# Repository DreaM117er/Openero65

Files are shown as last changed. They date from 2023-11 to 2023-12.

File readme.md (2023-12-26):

# OpeNero65

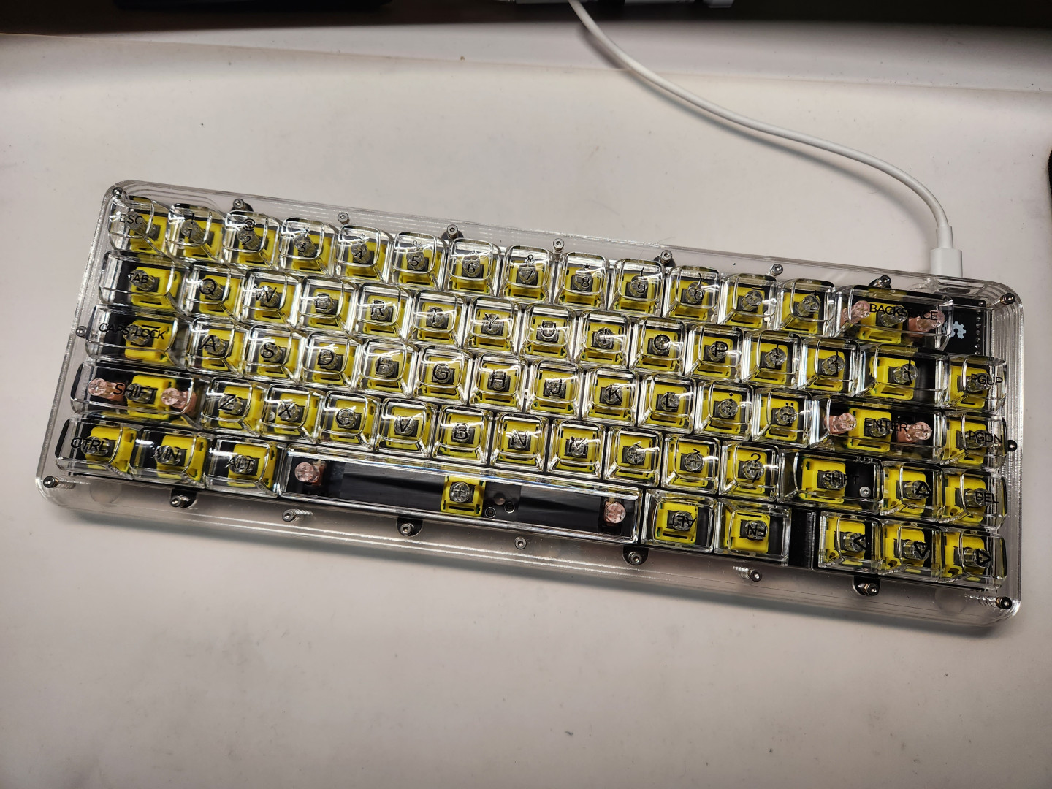
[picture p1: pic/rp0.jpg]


## 一、開發者前言

OpeNero65是我設計的第一把`ANSI配列`鍵盤，使用市面上都能輕易買到的RP2040開發板驅動，支援`QMK`/`VIAL`、多配列支持、階梯CapsLock等。本以為標準鍵盤外殼很好設計，後來發現單件CNC的價格過高，才改用堆疊外殼的設計方式，本次成品會採用3mm厚度壓克力製成。

OpeNero65 is the first `ANSI keyboard` I designed, it is driven by the RP2040 development board which can be easily purchased in the market, and it supports `QMK`/`VIAL`, multi-compatibility support, and ladder CapsLock, etc. Originally, I thought the standard keyboard case is very easy to design, then I found that the price of a single CNC is too high, so I switched to the stacked case design. Originally thought the standard keyboard case is very good design, but later found that the price of a single piece of CNC is too high, and then changed to the stacked case design, the finished product will be made of 3mm thickness acrylic.

設計堆疊殼也相當不輕鬆，特別是PCB階段它有一端是向外突起，接著開發板採用的是排針焊接固定，大大增加堆疊外殼的3D設計困難。仰角以堆疊外殼來說仰角有2種設計方式，但因為開發板固定在PCB上會有立體干涉存在，只能採用橫向堆疊的方式設計... 總體來說也經過一段時間折騰才順利完成。

The design of the stacked case is not easy, especially at the PCB stage it has an end that protrudes outward, and then the development board is fixed with rows of pins, which greatly increases the difficulty of the 3D design of the stacked case. Elevation angle to stack the case of the elevation angle of two design methods, but because the development board fixed on the PCB will have three-dimensional interference exists, can only be used in a horizontal stacking design... Overall, also after a period of time to successfully complete.

## 二、設計圖預覽

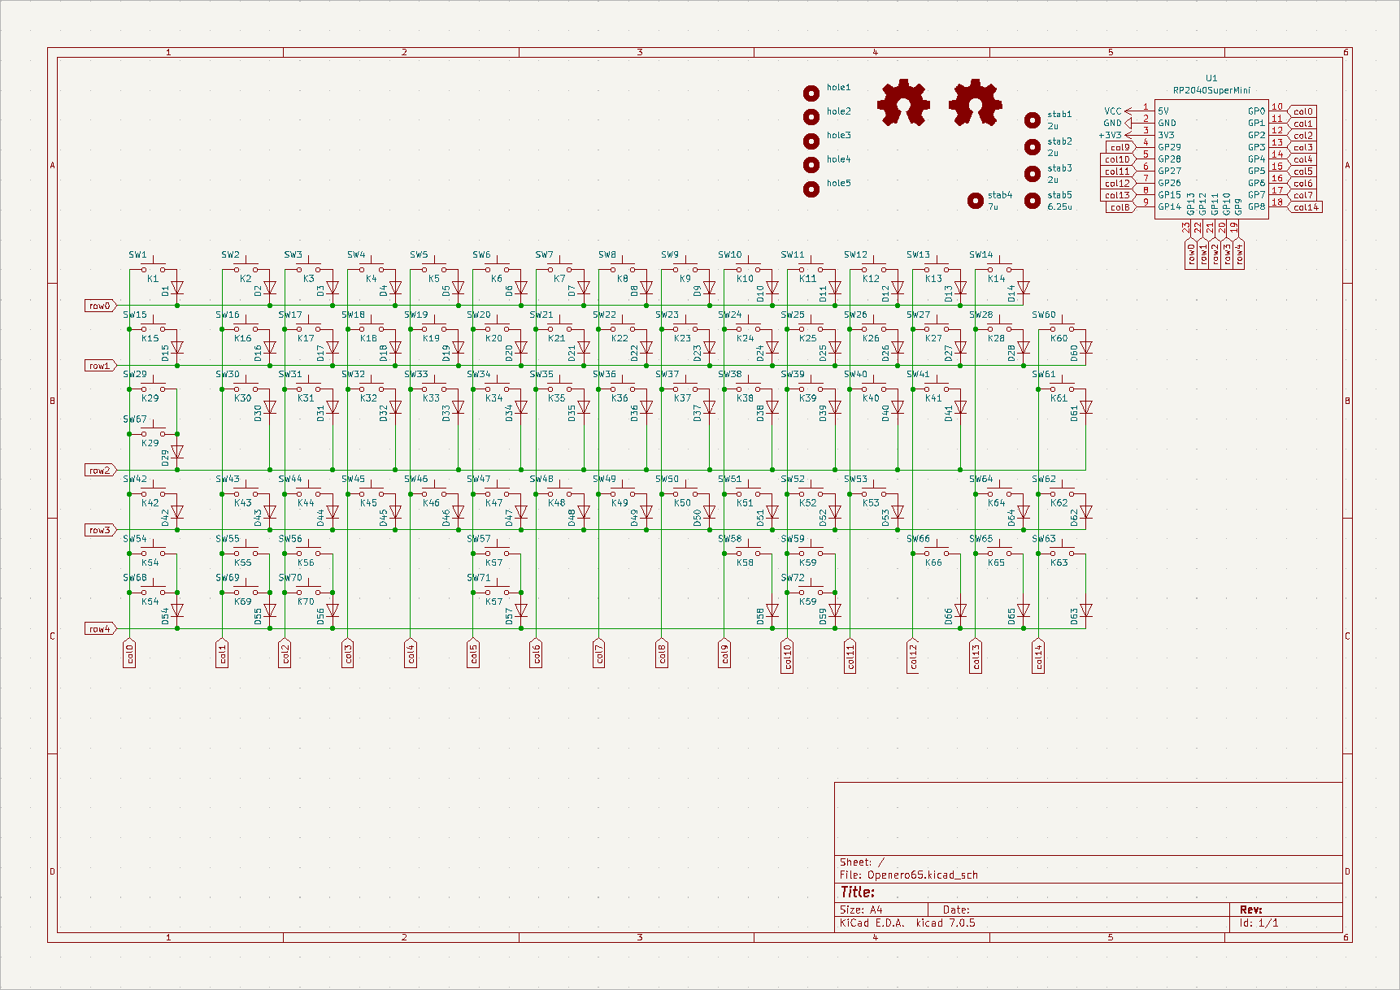
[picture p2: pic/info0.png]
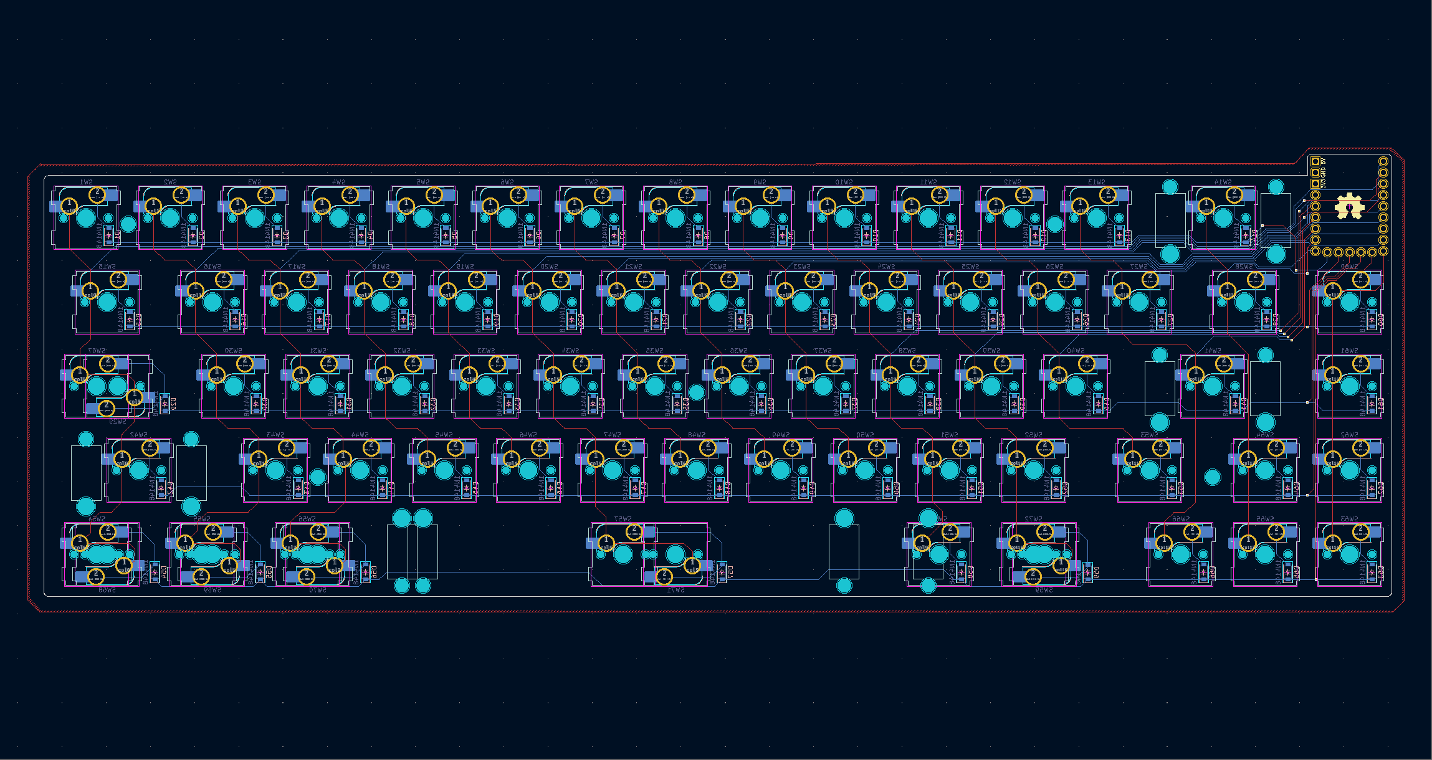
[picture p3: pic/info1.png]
|||
|---|---|
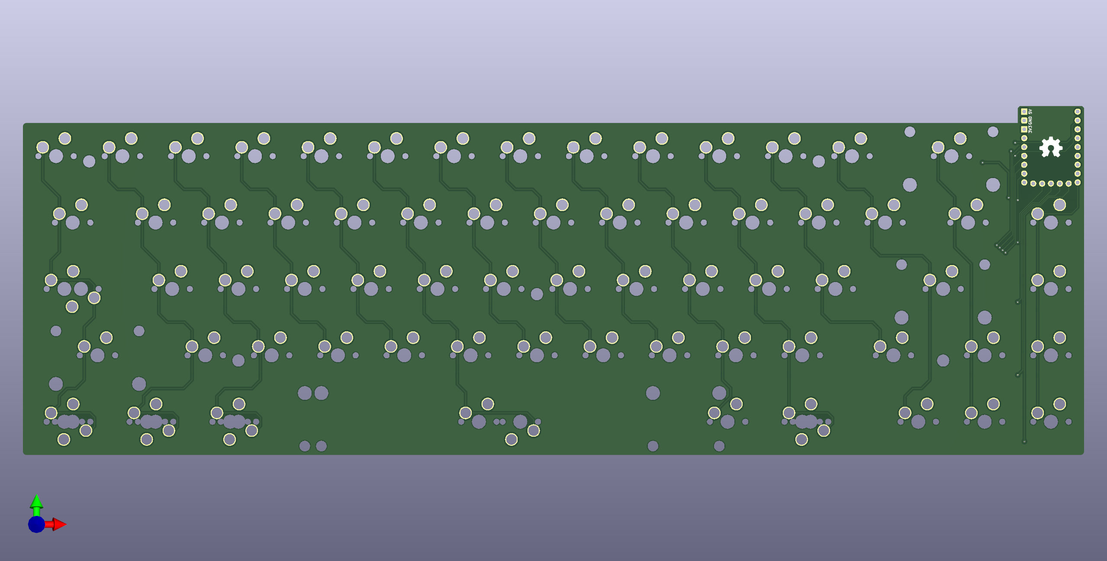
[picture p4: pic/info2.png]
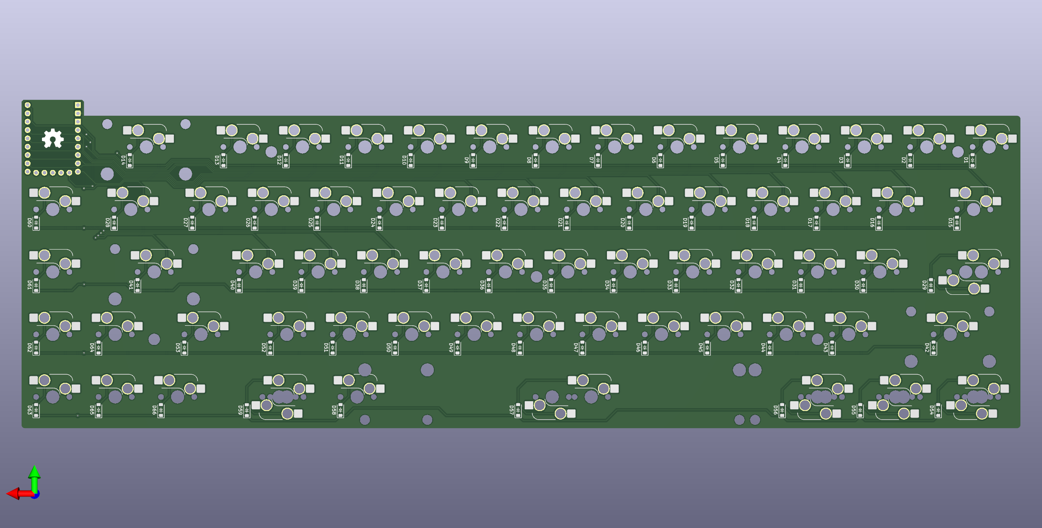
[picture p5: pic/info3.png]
|||
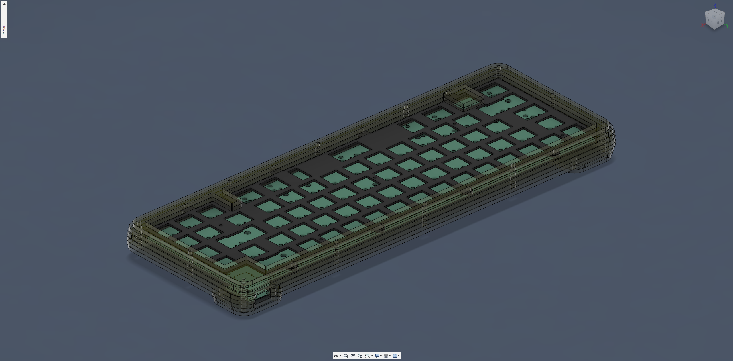
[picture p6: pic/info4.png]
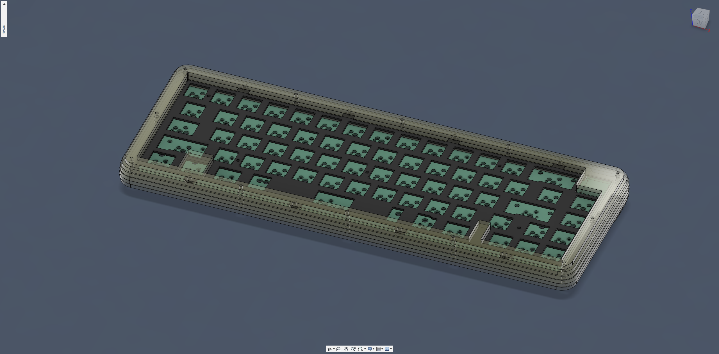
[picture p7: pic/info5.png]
|||
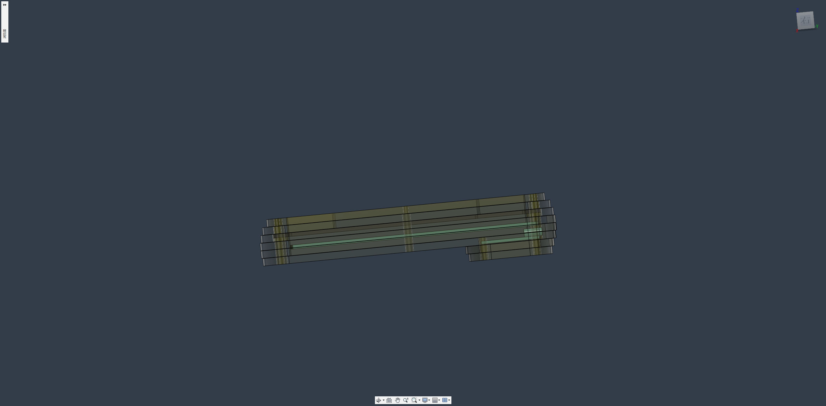
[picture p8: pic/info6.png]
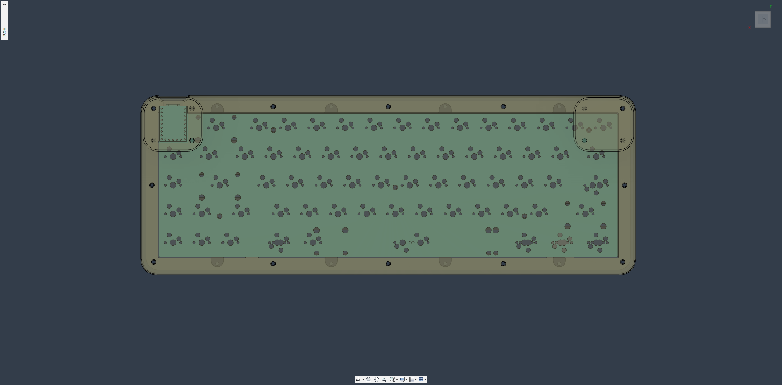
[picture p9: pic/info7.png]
|||

## 三、材料及使用工具

### A、材料：

|名稱|數量|備註|
|---|---|---|
|OpeNero65電路板（`PCB`）|1片|-|
|堆疊外殼（Stacking Case）|1組|10片堆疊材料|
|微控制器（`MCU`）|1片|`RP2040Supermini`、`RP2040Zero`|
|公母圓排針（M/F Pin header）|`9pin`、`5pin`|選配（`Optional`）|
|熱插拔座（Hotswap Sockets）|72個|`MX`規格（for MX switches）|
|`M2x5mm` 扁頭螺絲（Screws）|30根|-|
|`M2x4mm` 扁頭螺絲（Screws）|8根|-|
|`M2x3mm` 扁頭螺絲（Screws）|20根|-|
|`M2x18mm` 雙通銅柱（Spacer）|2根|-|
|`M2x12mm` 雙通銅柱（Spacer）|10根|-|
|`M2x5mm` 雙通銅柱（Spacer）|11根|-|
|`M2x3mm` 雙通銅柱（Spacer）|8根|-|
|`PCB`衛星軸（Stablizers）|3+1組|`2u`、`6.25u`/`7u`|
|衛星軸用潤滑酯|-|`Permatex 22058`/`81150`或`XHT-BDZ`|
|防滑腳貼（Rubber feets）|5個|高度隨個人而定|
|外徑`5mm` 內徑`2mm` 橡膠圈（Outer `ø5mm`, inner `ø2mm` O-rings）|15個|選配（`Optional`）|
|`M2` 防滑墊片（`M2` washers）|5個|選配（`Optional`）|

### B、使用工具：

- 電烙鐵及相關工具組（Solder gun and other packs）。
- 精密螺絲起子組（Screwdriver set）。
- 防靜電金屬鑷子（Anti-static metal tweezers）。
- 拔鍵器（Keycaps puller）。
- 拔軸器（Keyswitch puller）。
- 細毛毛刷（Brushes for stablizers）。

### C、注意事項：

> **Warning**
>
> 使用電烙鐵時注意用電、用火安全，環境通風。
> 
> Be carefull on fire and electricity safety when soldering in environmental ventilation.

> **Warning**
>
> 定製外殼前務必瞭解自身需求的鍵盤佈局（例如6.25u、7.00u Spacebar；WK、WKL等）。
> 
> Please understood which keyboard layout you need before making/ordering case. (ex: 6.25u, 7.00u spacebar; WK, WKL...)

> **Warning**
>
> 在定製製作Openero65外殼之前一定要特別注意，壓克力板一定會有`0.1-0.35mm`左右的公差存在，成品會比實際用計算機計算來的小一些。
> 
> Before you oeder cases from factory, arcylic boards must exist tolerances about `0.1-0.35mm`, the finished product will be smaller than the actual calculator.

> **Warning**
>
> 請準備個人喜歡的MX鍵軸65-66顆，以及調整衛星軸鋼絲的前置動作。
> 
> Please prepare 65-66 personal MX switches and adjusted stablizer wires before building keyboard.

材料及工具準備好之後，點我前往[組裝說明](guide.md)。

## 四、參考及使用資料
- [QMK Firmware](https://qmk.fm/).
- [VIAL](https://get.vial.today/).
- [KiCAD](https://www.kicad.org/) version `7.0.5.`
- [JLCPCB](https://jlcpcb.com/).
- [DeepL](https://www.deepl.com/translator).
- [AutoDesk Fusion360](https://www.autodesk.com/products/fusion-360/free-trial).
- Taiwan [Tatung University](https://www.ttu.edu.tw/) - [Department of Mechanical and Materials Engineering](https://mme.ttu.edu.tw/)
- And my friend: [YCT](https://github.com/yct38)

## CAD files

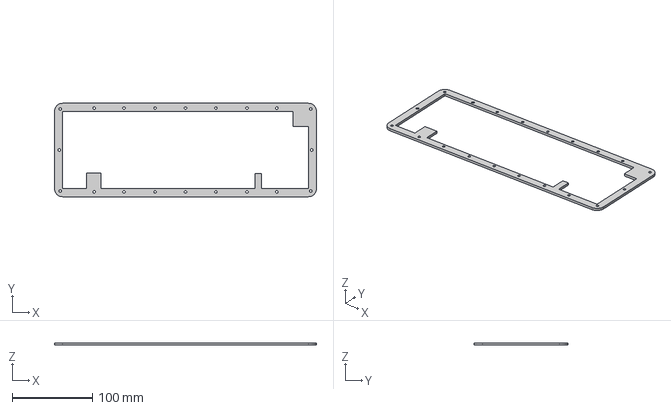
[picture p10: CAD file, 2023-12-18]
files/v1/case/1.00_wkl/2.step
325.9 x 116.3 x 3.00 mm

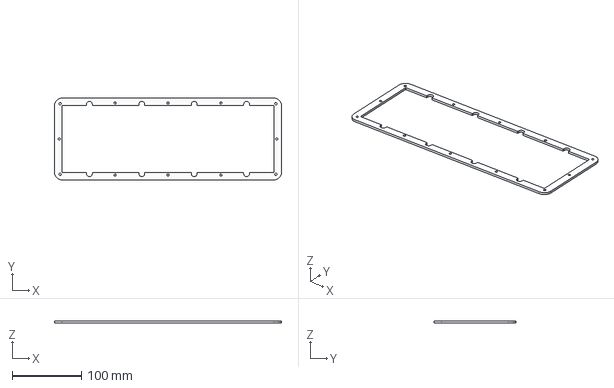
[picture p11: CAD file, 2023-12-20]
files/v1/case/3.step
327.9 x 118.3 x 3.00 mm

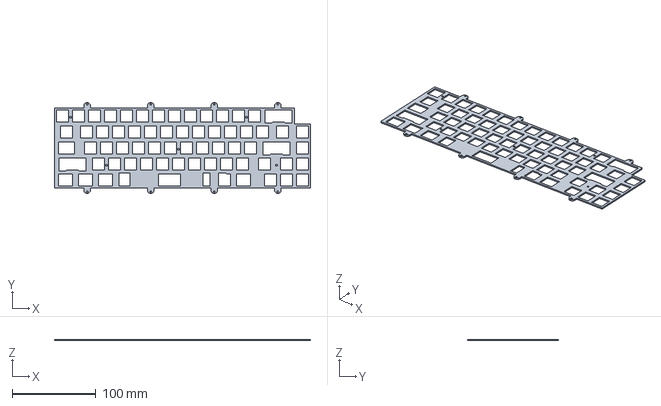
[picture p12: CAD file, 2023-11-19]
files/v1/plate.step
304.8 x 108.3 x 1.50 mm

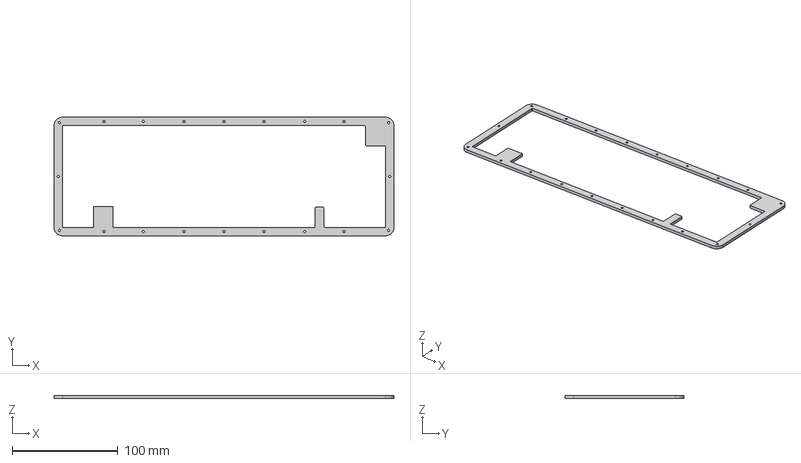
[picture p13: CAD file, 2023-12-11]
files/v1/case/1.00_wkl/1.step
321.9 x 112.3 x 3.00 mm

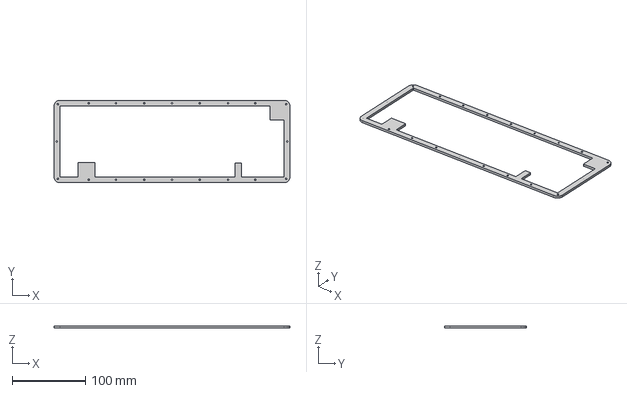
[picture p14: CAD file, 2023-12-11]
files/v1/case/1.25_wkl/1.step
321.9 x 112.3 x 3.00 mm

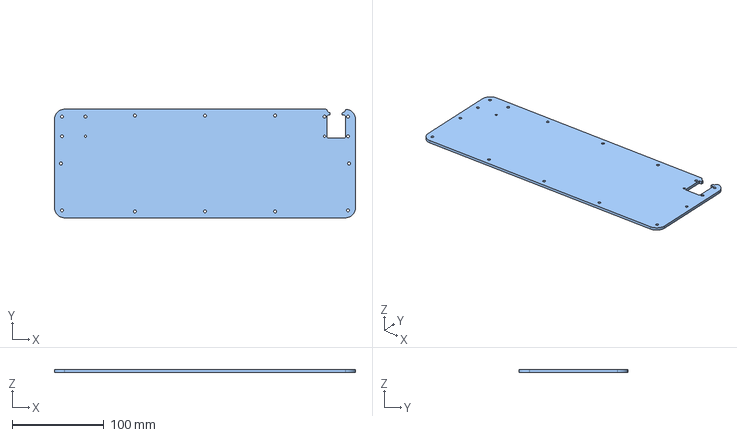
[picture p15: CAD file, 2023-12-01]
files/v1/case/6.step
327.9 x 118.3 x 3.00 mm

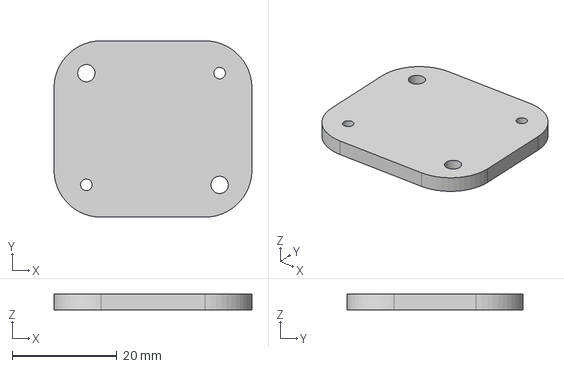
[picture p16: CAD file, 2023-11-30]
files/v1/case/8-1.step
37.8 x 33.7 x 3.00 mm

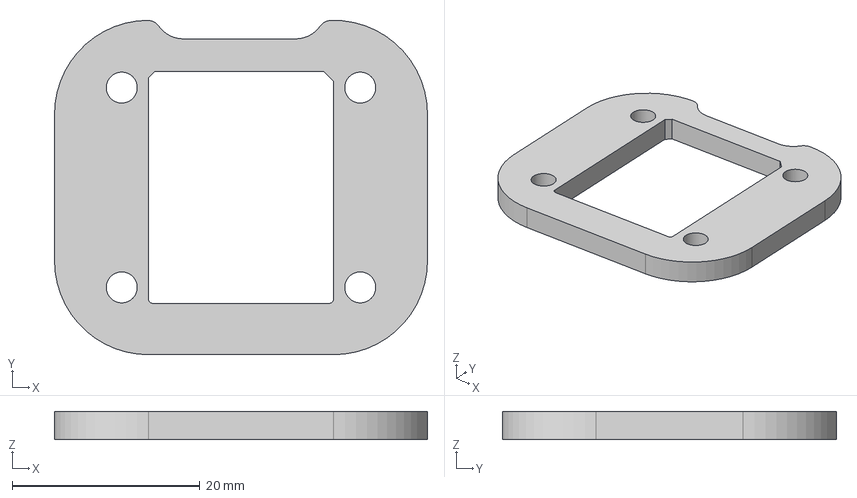
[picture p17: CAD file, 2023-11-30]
files/v1/case/7-2.step
39.8 x 35.6 x 3.00 mm

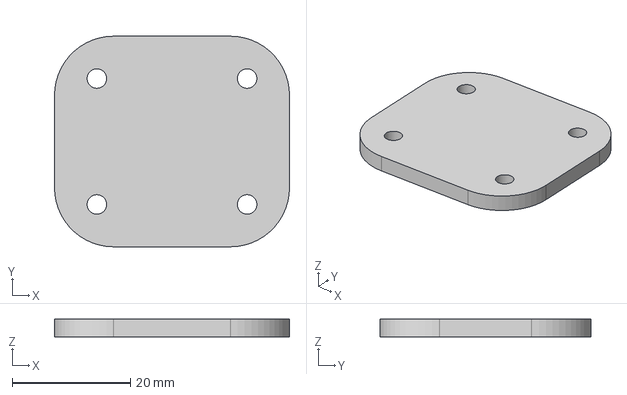
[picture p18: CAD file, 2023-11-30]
files/v1/case/7-1.step
39.8 x 35.7 x 3.00 mm

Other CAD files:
files/v1/case/1.25_wkl/2.step
files/v1/case/wk/2.step
files/v1/case/4.step
files/v1/case/wk/1.step
files/v1/case/5.step
files/v1/case/8-2.step

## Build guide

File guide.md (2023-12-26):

# 組裝說明 Building Guide

- 電路板及定位板。
- PCB and plate.

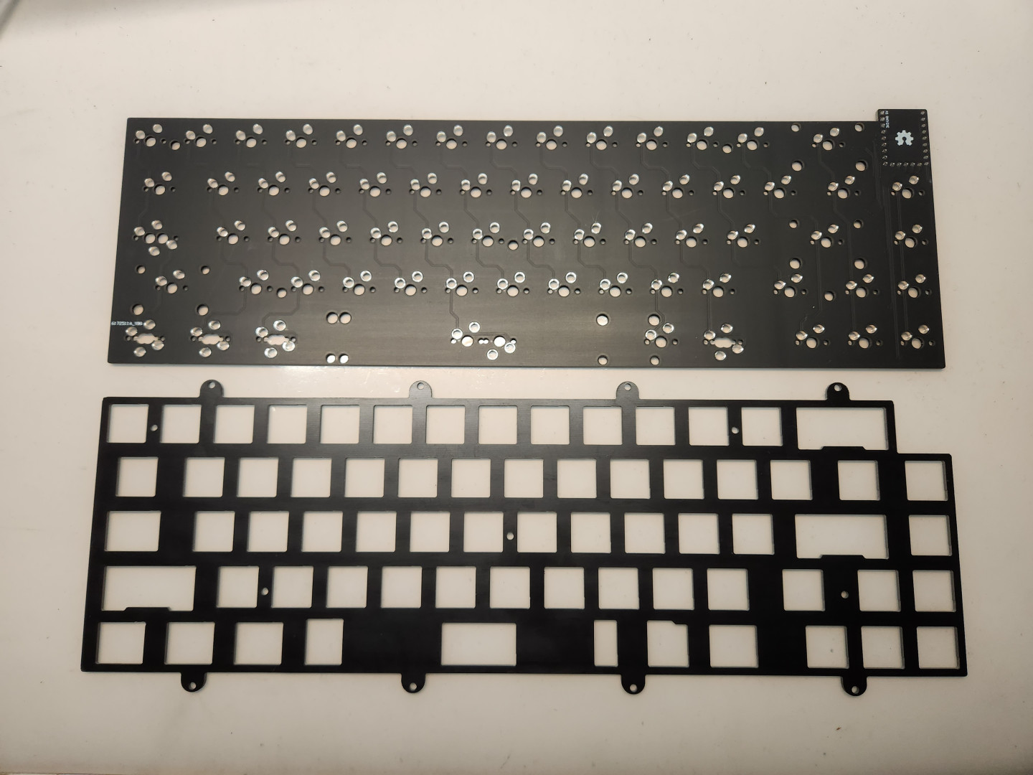
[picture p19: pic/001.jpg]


## 一、韌體燒錄（Firmware）

- 首先將韌體燒錄進MCU中預備，方法如下：
- First you need to flash firmware into MCU, please follow step below：

> **Note**
>
> RP2040 SuperMini/Zero系列有著跟一般RP2040 Pico一樣的燒錄韌體方法，首先你要壓著MCU上頭的`Bootloader按鈕`，再將MCU接上電腦，之後電腦本機上會出現一個`專屬的硬碟`，再將鍵盤的`.uf2`韌體丟進去就可以了。
>
> RP2040 SuperMini/Zero have same `bootloader` way, you need to keep pushing switch on the MCU `before` plug USB-C cable to the PC. After that, you can see a `disk` on your device, then put `.uf2` firmware file into disk.

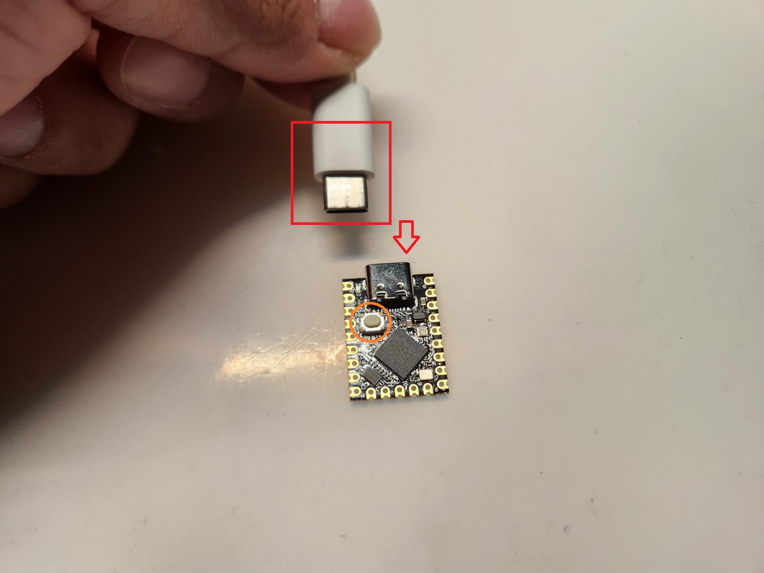
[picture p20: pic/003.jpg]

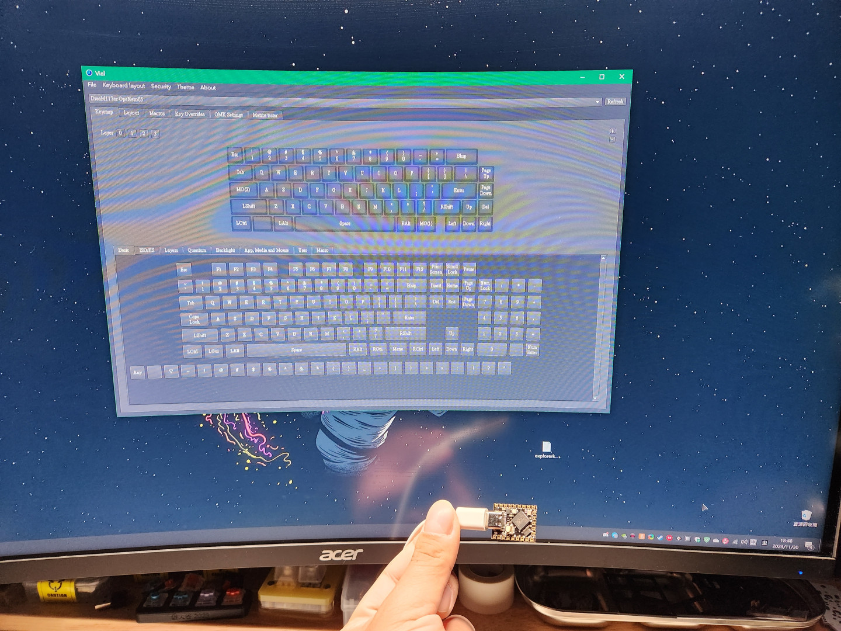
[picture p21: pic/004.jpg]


## 二、二極體&熱插拔座&排針（Diodes and Hotswap sockets and Pin headers）

- 接著準備好PCB、二極體及熱插拔座，並且依序按照電路板上的方向焊接固定起來。
- Prepared the PCB, diodes and hotswap sockets, soldering and fixing in the direction of the PCB.

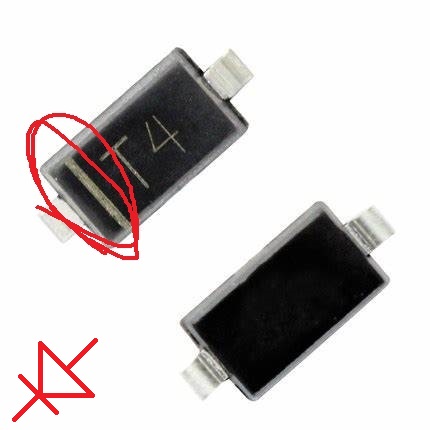
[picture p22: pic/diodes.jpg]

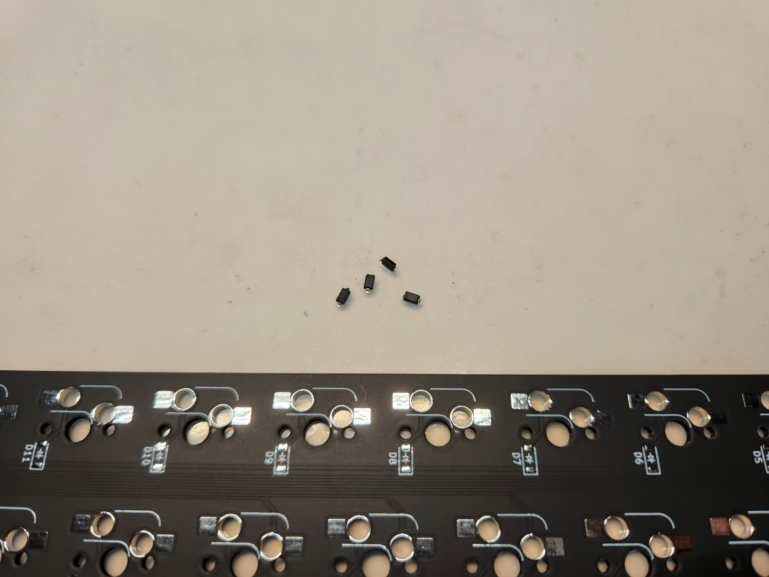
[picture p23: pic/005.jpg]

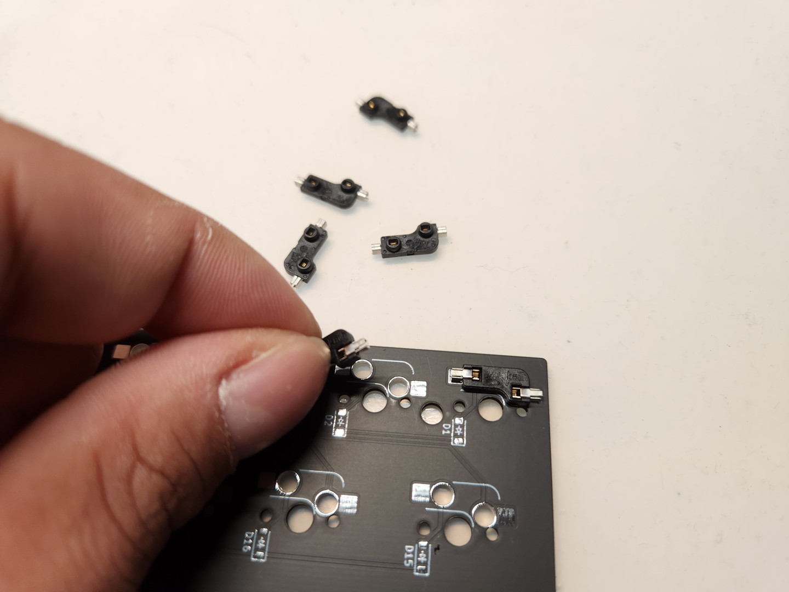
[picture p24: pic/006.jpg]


- 接下來準備排針及MCU，對照好PCB上的腳位，將排針安裝在PCB的背面。
- Prepare pin headers and MCU, following and installing them in the direction of the PCB on back side.

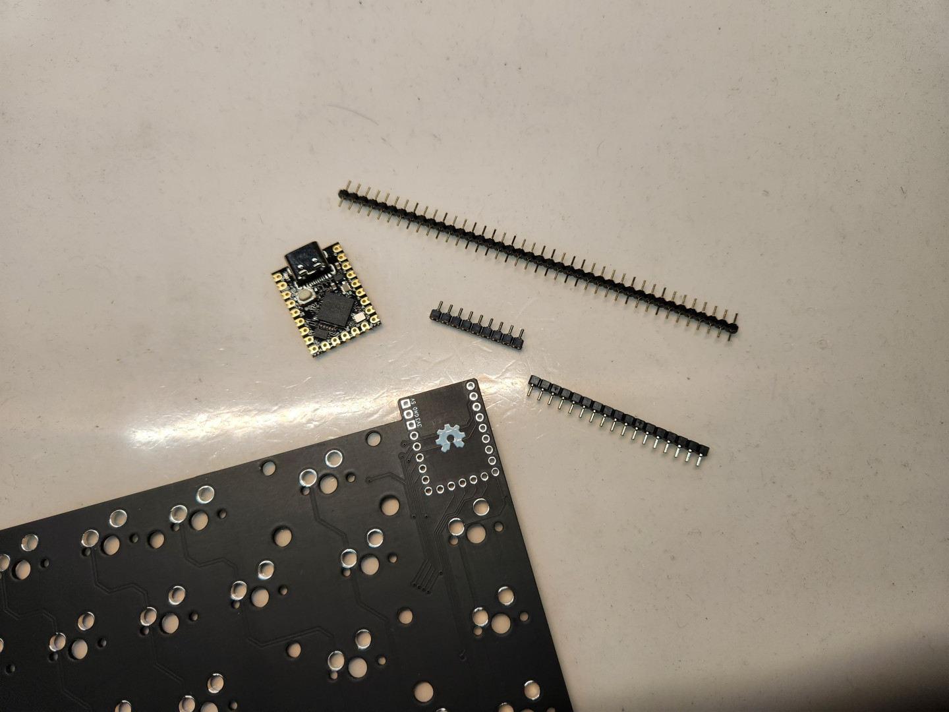
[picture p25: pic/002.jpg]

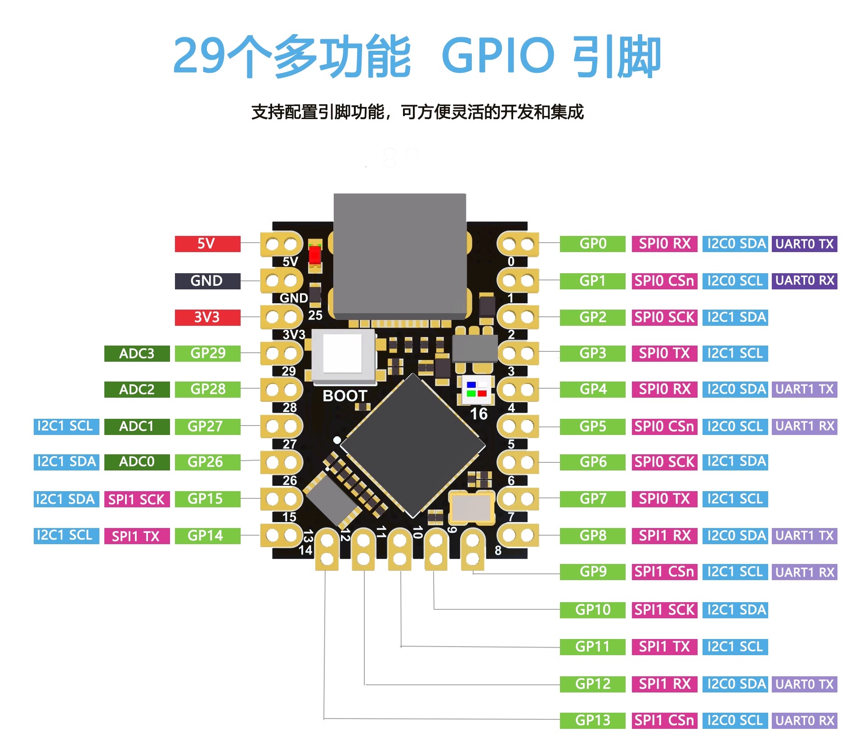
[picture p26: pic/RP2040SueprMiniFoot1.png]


- 推薦先安裝母排針，再安裝公排針，再將MCU放上去固定好後再進行焊接。
- It is recommended to install the female pins first, then the male pins, then put the MCU on it and fix it before soldering.

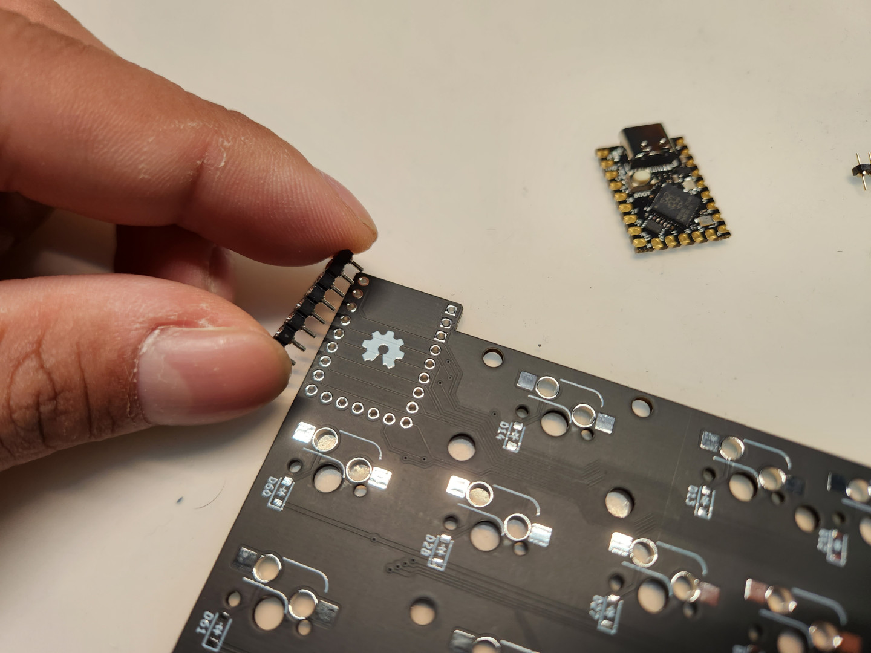
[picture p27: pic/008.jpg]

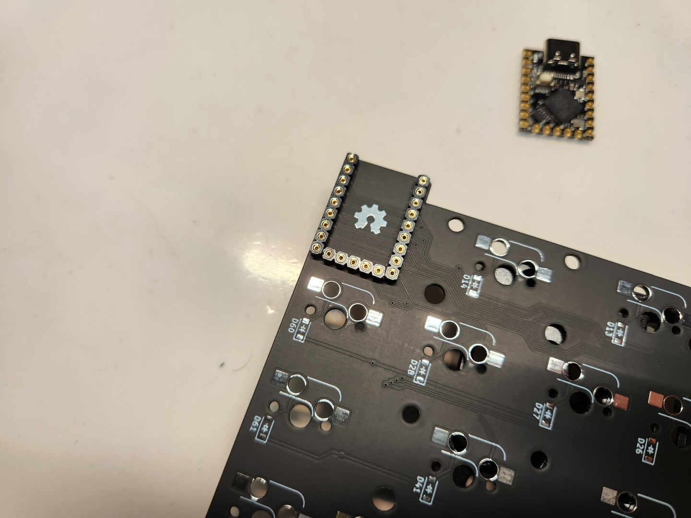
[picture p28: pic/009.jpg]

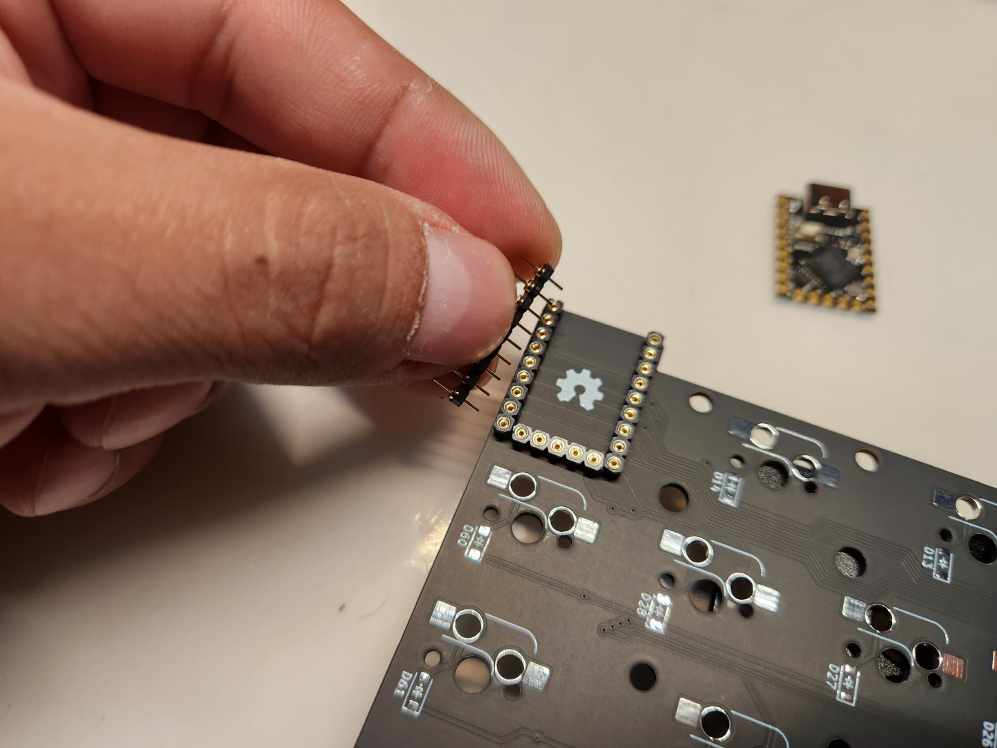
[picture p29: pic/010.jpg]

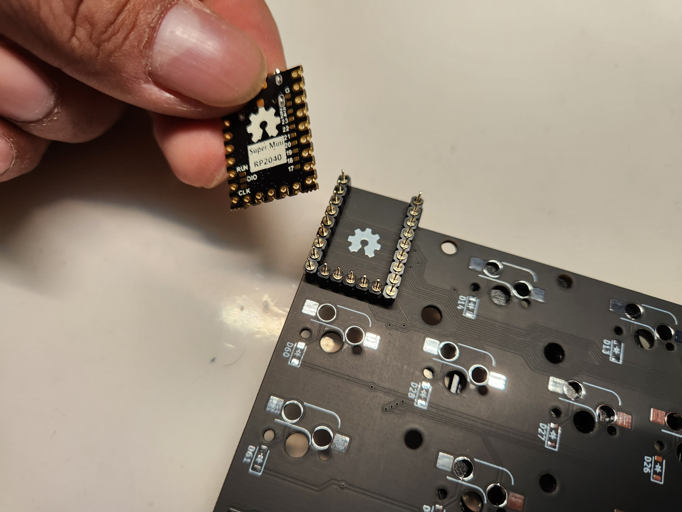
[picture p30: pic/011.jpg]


- 熱插拔座、二極體、MCU安裝好之後會是這個樣子。
- IF you finished installing hotswap sockets, diodes and MCU, check picture, it finally looks like the picture below.

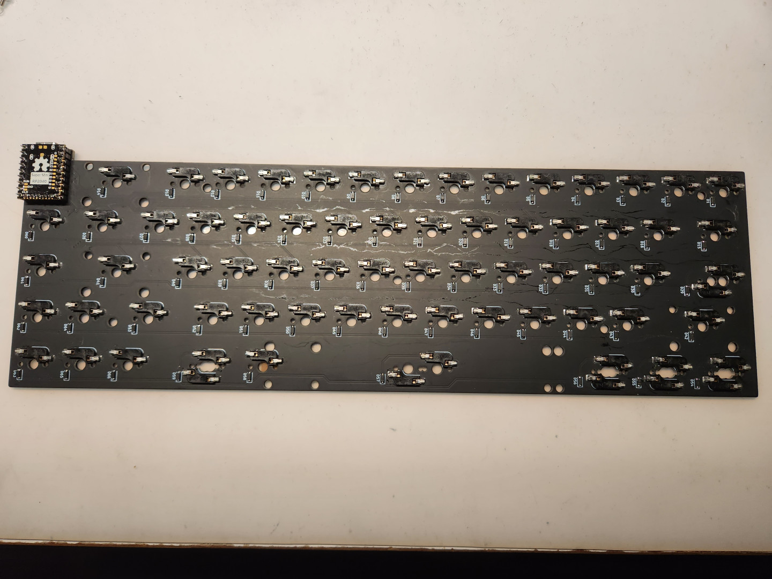
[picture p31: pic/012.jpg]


## 三、衛星軸&定位板（Stablizers and Plate）

> **Note**
>
> 以我的鍵盤經驗來看，真的很多人不懂如何組裝及安裝衛星軸，再不調整鋼絲的情況下，這裡我會將完整的組裝步驟交付給大家。
>
> From my keyboard experience, really many people don't know how to assemble and install the stablizers without adjusting the wires again, here I will show the complete assembly steps to you.

- 首先準備好一組衛星軸的部件及衛星軸油脂，這裡我是使用針筒包裝的XHT-BDZ。
- First you need to prepare one set of stablizer and oil, here I use XHT-BDZ for example.

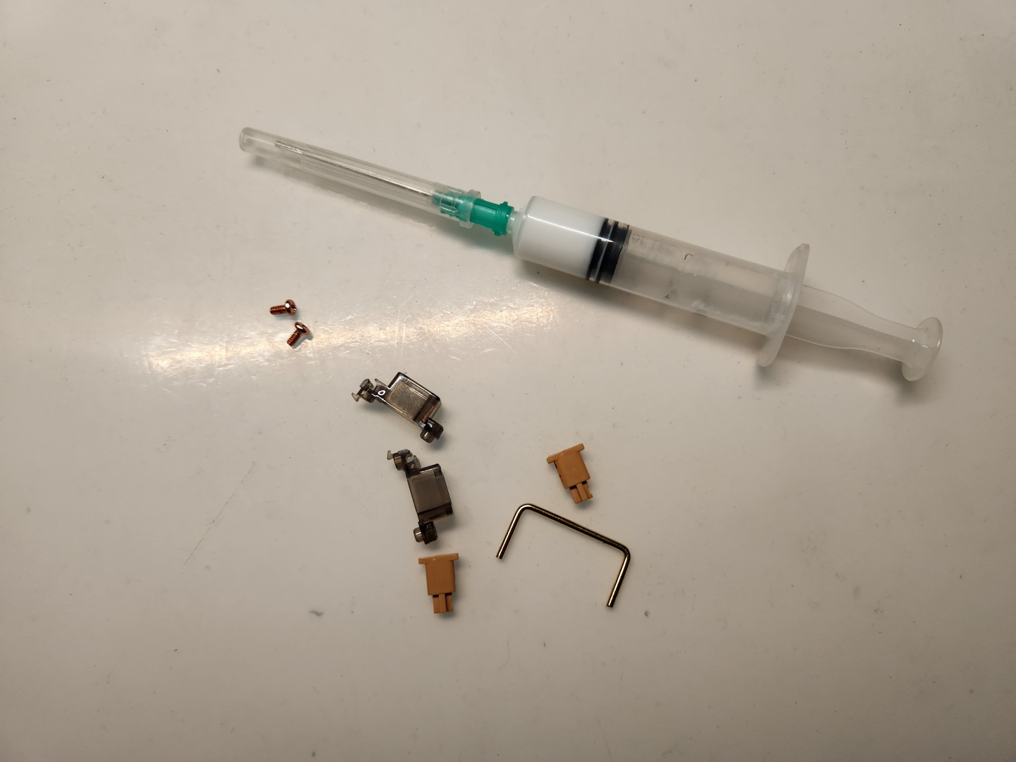
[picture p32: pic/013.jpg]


- 假軸軸心底部及外殼上會有缺口做防呆，安裝時直接將軸心跟外殼做合併。
- There are notches on the bottom of the stem and on the housing for durability, so that the stem and the housing can be merged directly during installation.

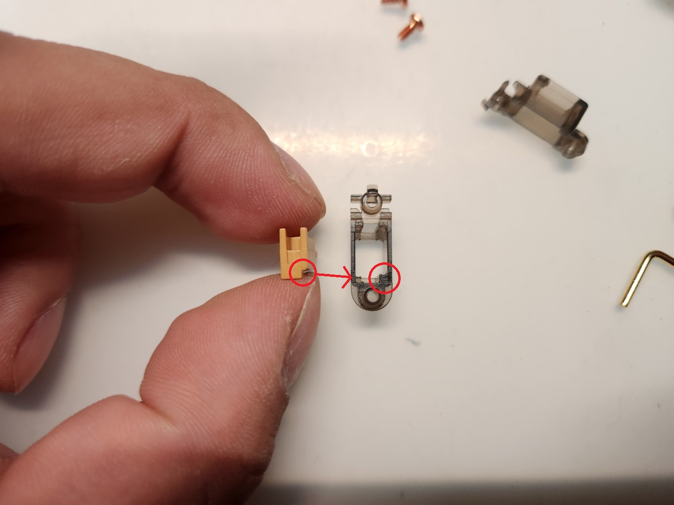
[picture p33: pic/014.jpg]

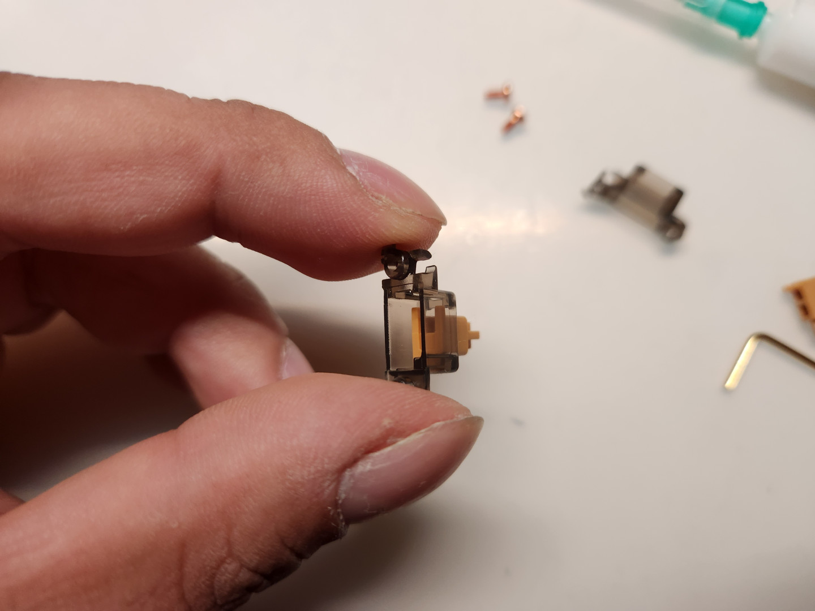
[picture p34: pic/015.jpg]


- 接著將鋼絲一端放入假軸軸心的孔洞中，如照片所示。
- Then you need to put stablizer wire in the hole on stem, like pictures below.

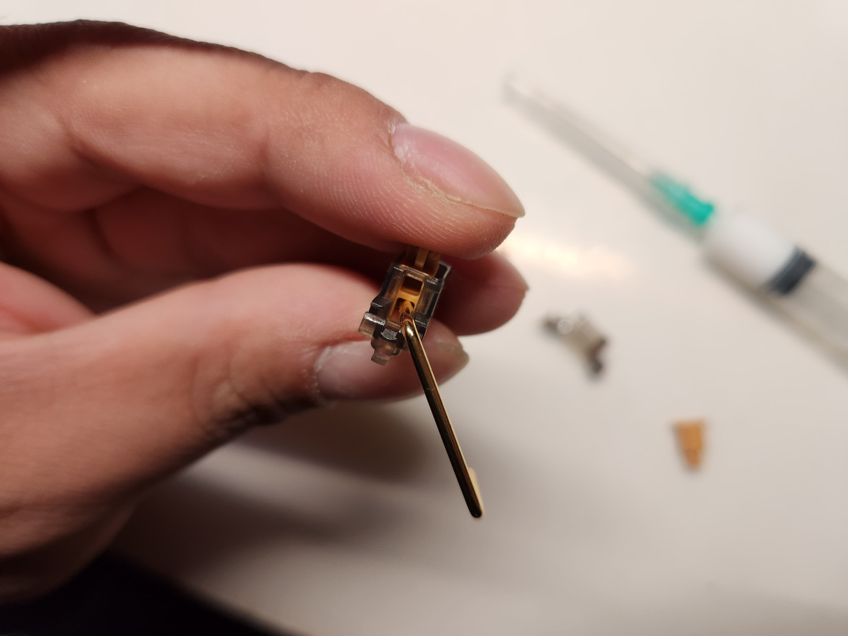
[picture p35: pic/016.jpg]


- 最後將鋼絲固定在外殼上的卡扣處，衛星軸的兩端都一樣。
- Finally, fasten the wire to the clips on the outer housing, the same for both ends of the stablizer.

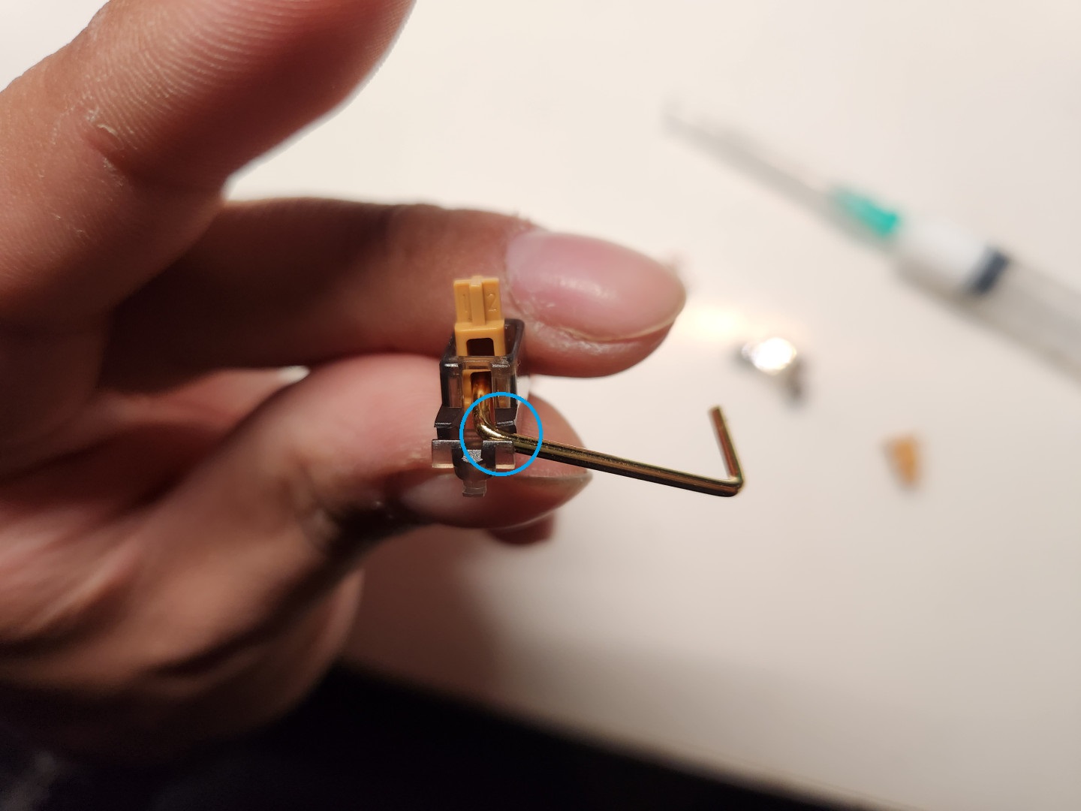
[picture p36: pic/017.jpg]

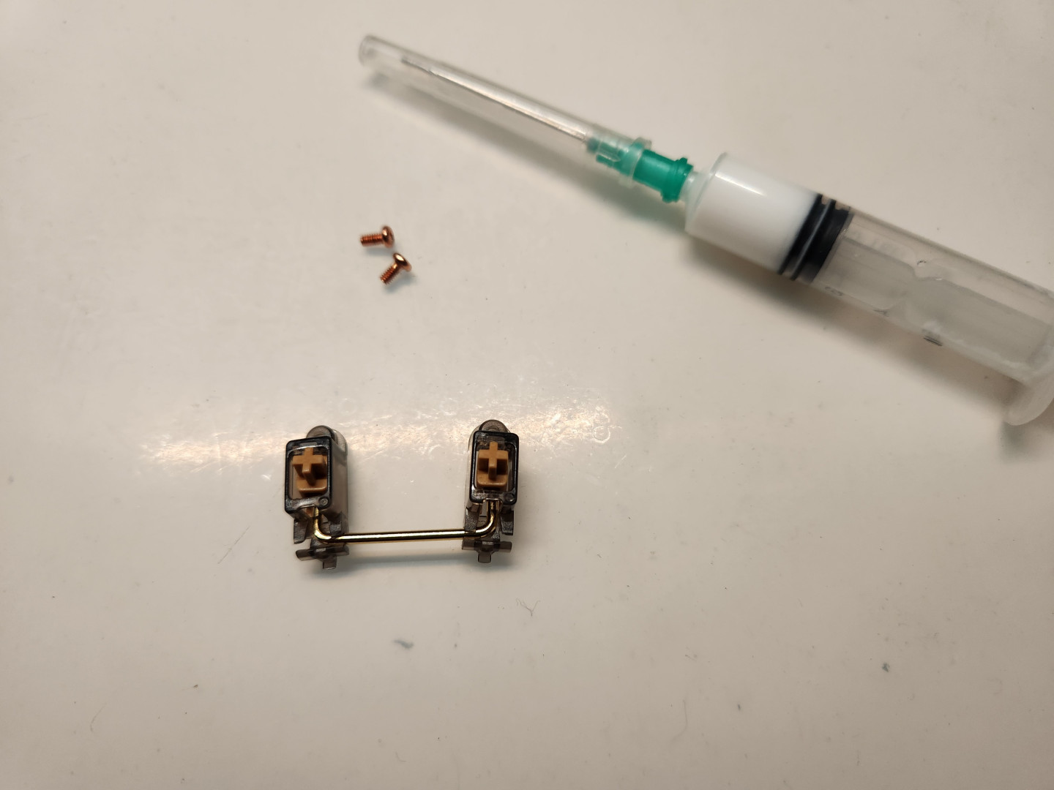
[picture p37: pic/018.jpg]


- 接著將衛星軸潤滑脂添加在衛星軸內部即可。
- Then add `XHT-BDZ` to the inside of the stablizer stem holes.

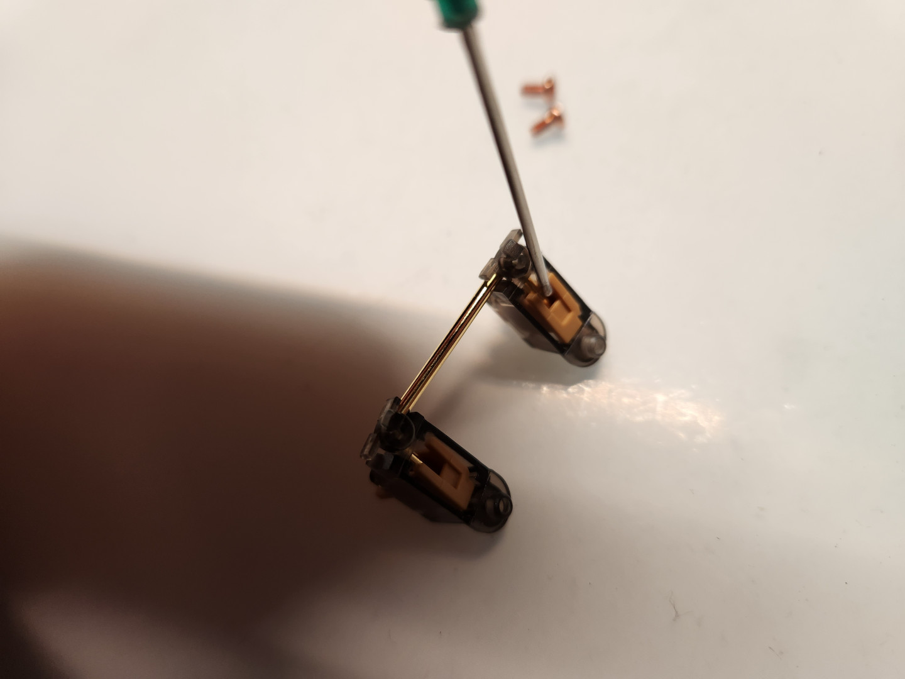
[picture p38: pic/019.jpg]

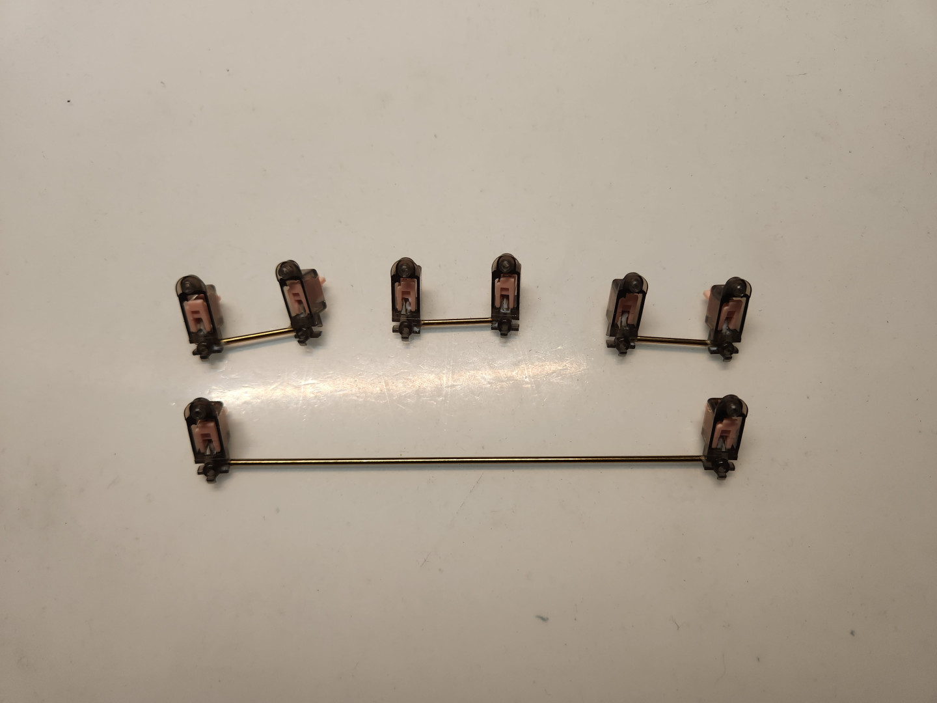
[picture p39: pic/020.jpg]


- 準備好適合Openero65數量的衛星軸後，將他們安裝到PCB上。（這裡使用鐵氟龍膠帶貼在衛星軸假軸與PCB的接觸面，減緩衛星軸撞擊PCB的影響。）
- After prepare `3+1 sets` of steblizers, you need to install them on the PCB. (Here, Teflon tape is used to affix to the contact surface between the stem dummy and the PCB to mitigate the impact of the stem hitting the PCB.)

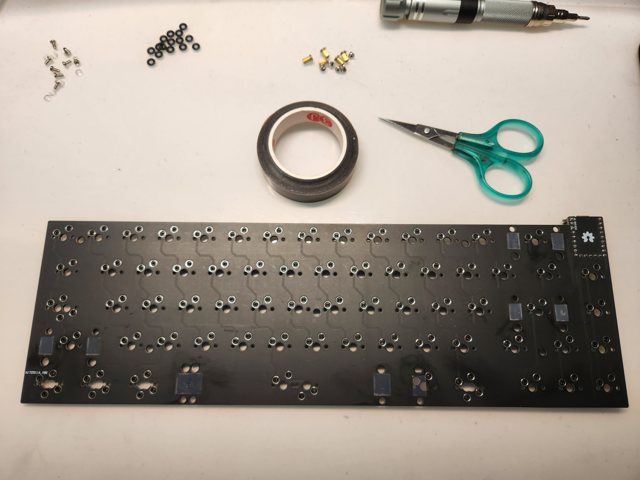
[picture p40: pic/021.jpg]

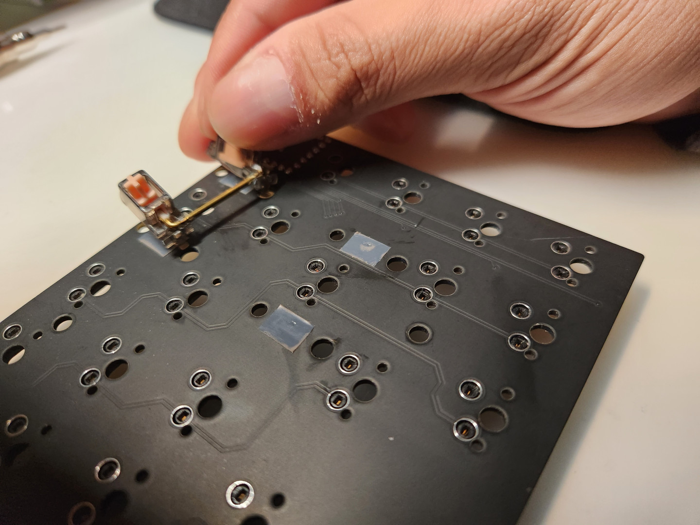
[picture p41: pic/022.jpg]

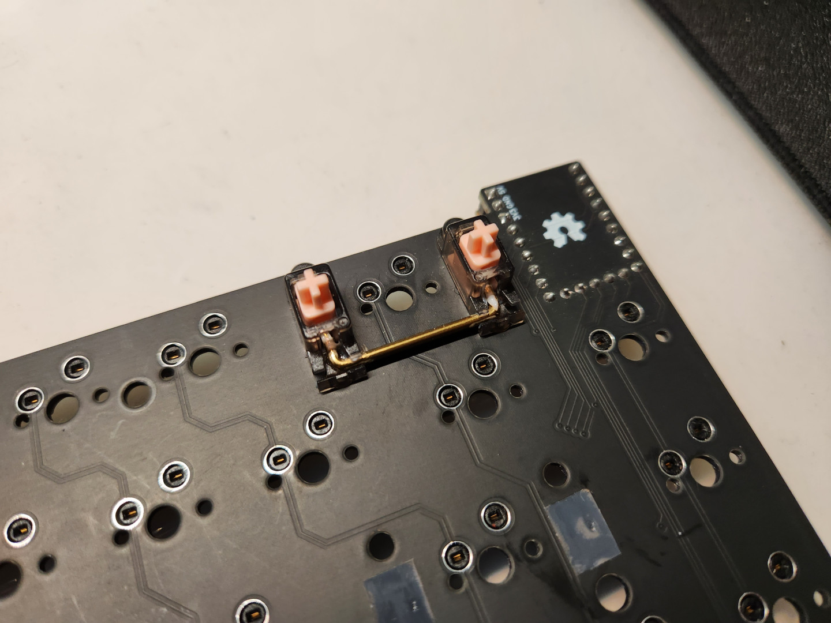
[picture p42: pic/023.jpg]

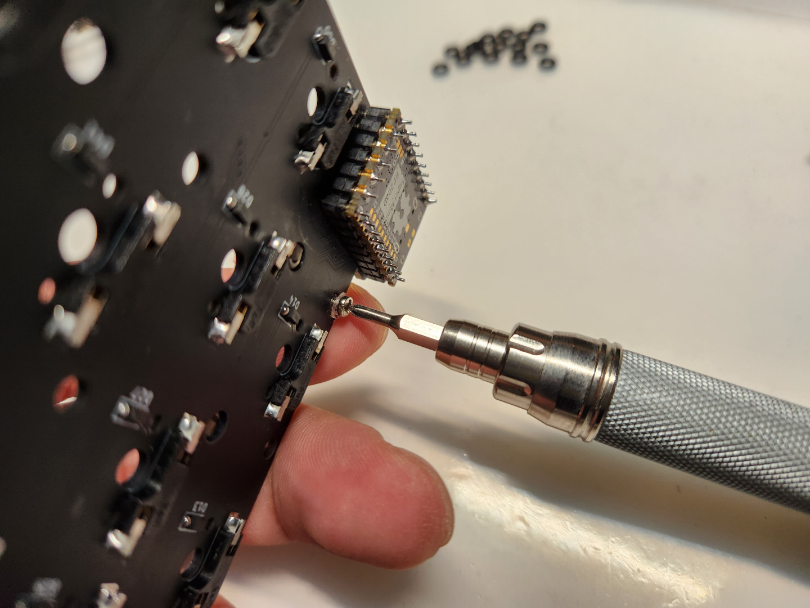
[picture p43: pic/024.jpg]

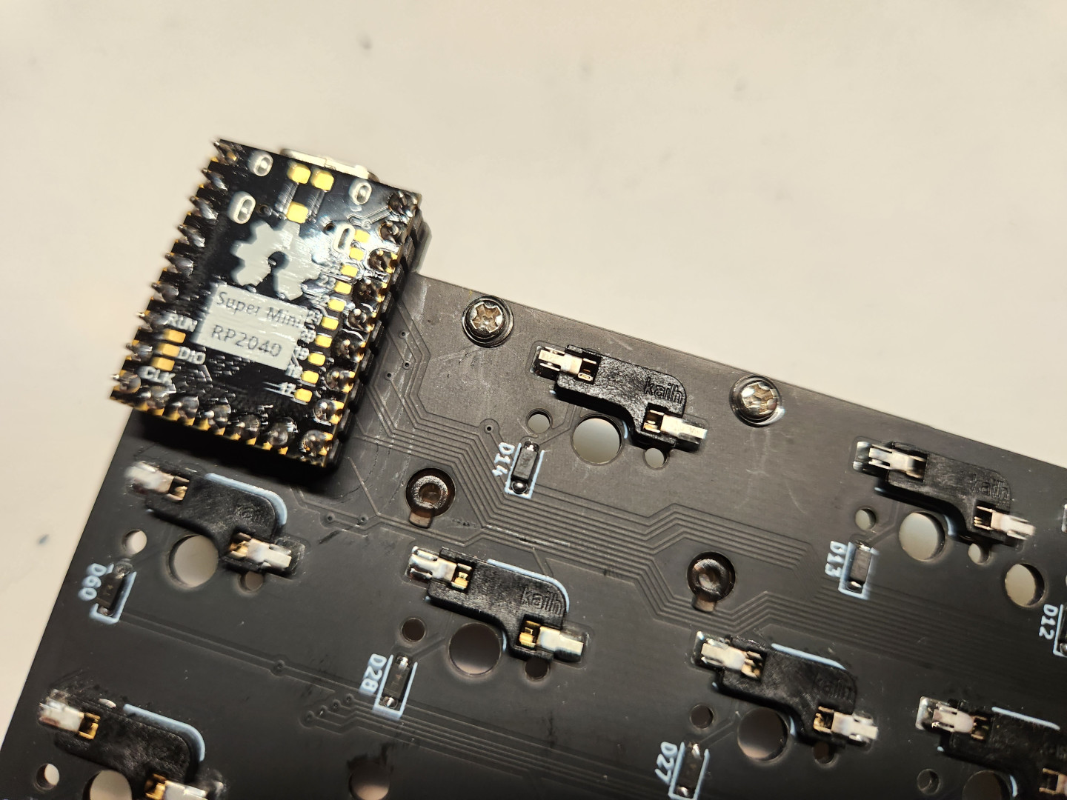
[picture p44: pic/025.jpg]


- 這樣衛星軸就安裝完成了。
- That you finished to install stablizers.

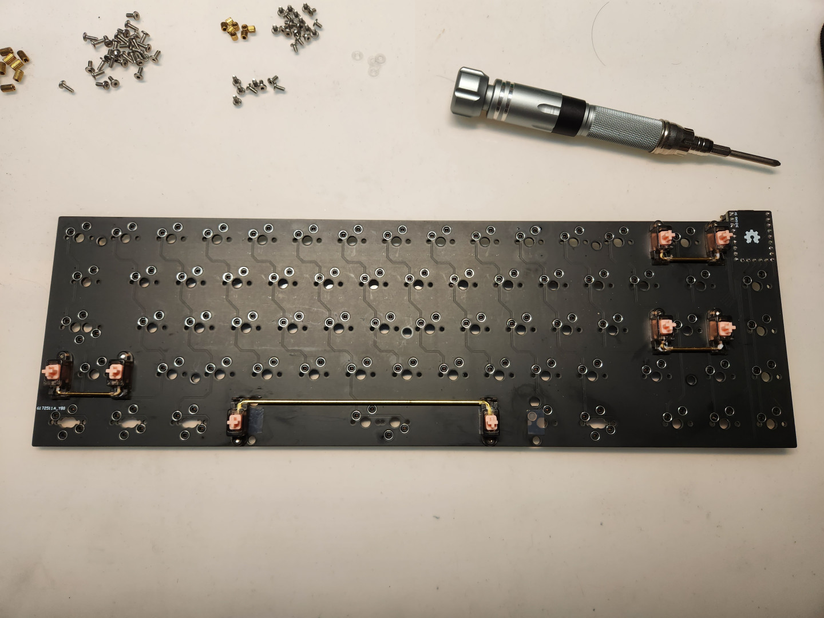
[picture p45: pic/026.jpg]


- 這裡首先將定位板、`M2x3mm螺絲`及`M2x5mm銅柱`準備好，依照照片的方法將銅柱固定在定位板上。
- Here, first prepare the plate, `M2x3mm screws` and `M2x5mm spacers`, and fix the spacers on the plate according to the method shown in the photo.

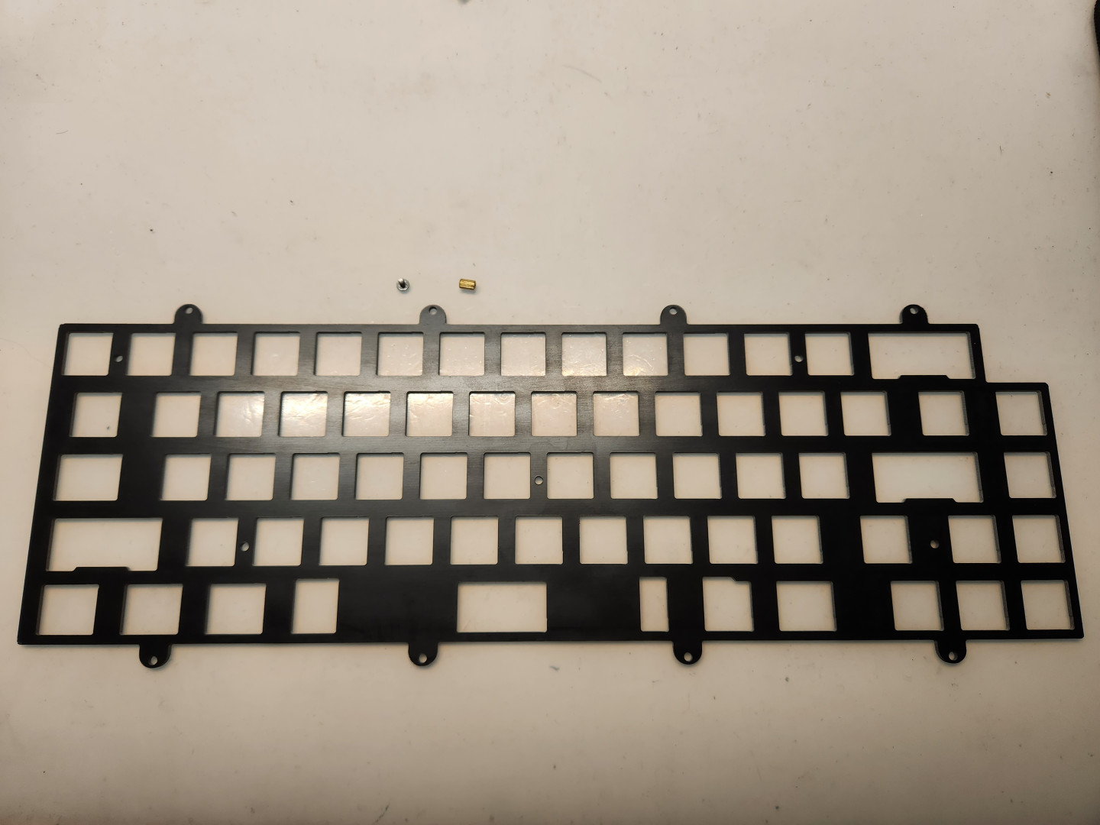
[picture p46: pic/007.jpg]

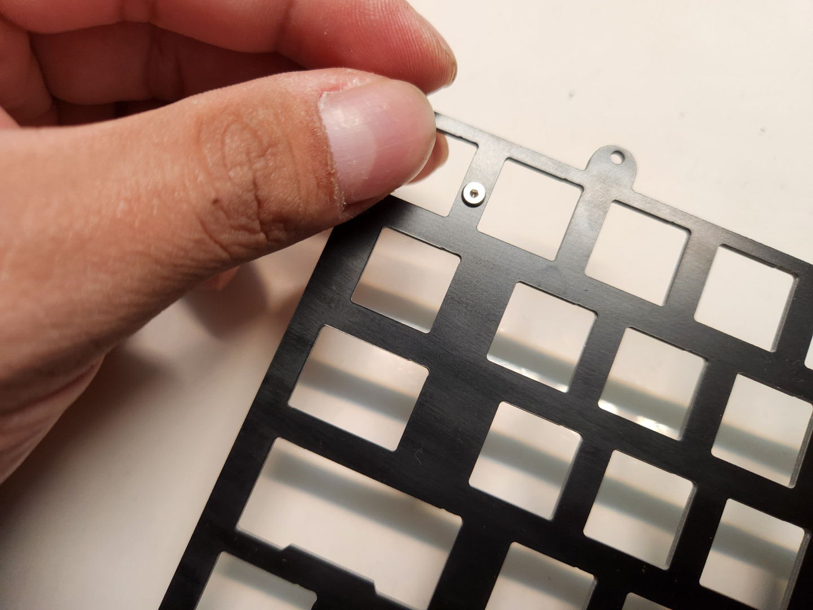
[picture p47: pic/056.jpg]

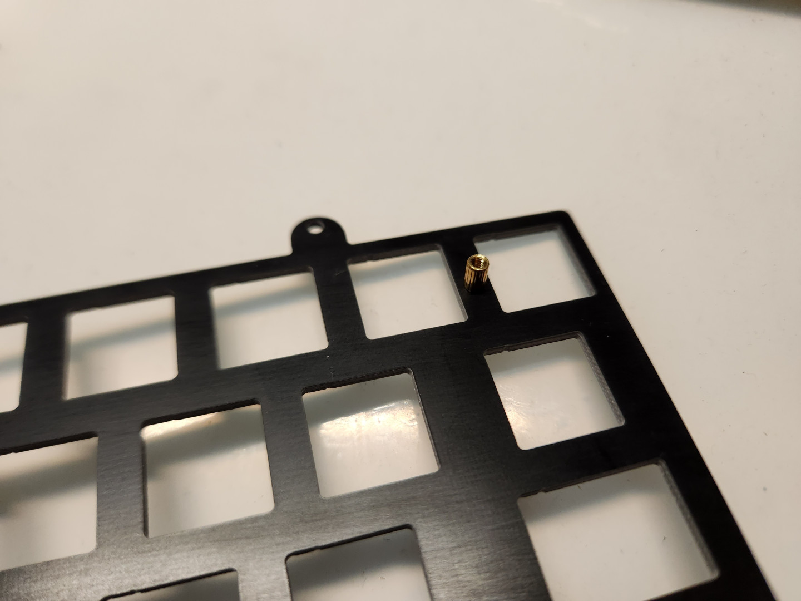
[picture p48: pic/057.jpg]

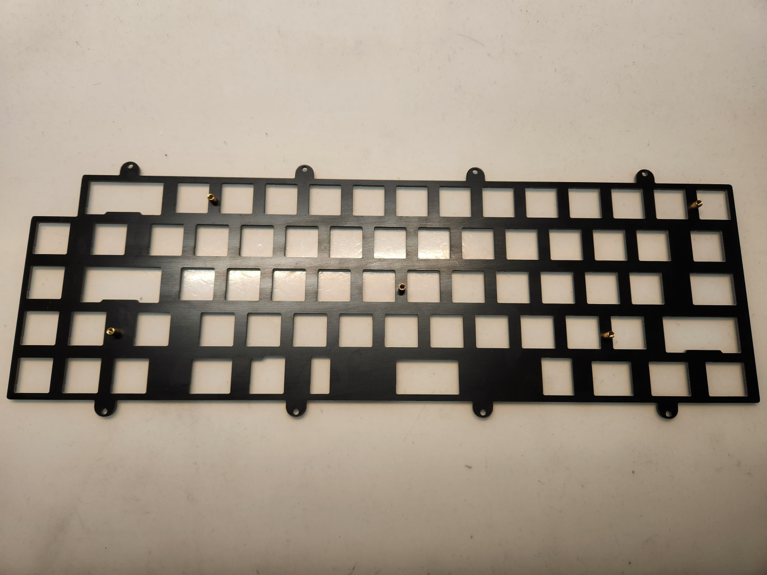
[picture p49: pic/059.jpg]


- 再來將15個橡膠圈以3個為一組平均分配在5個銅柱上。
- Distribute the `15 O-rings` in groups of 3 evenly among the 5 spacers.

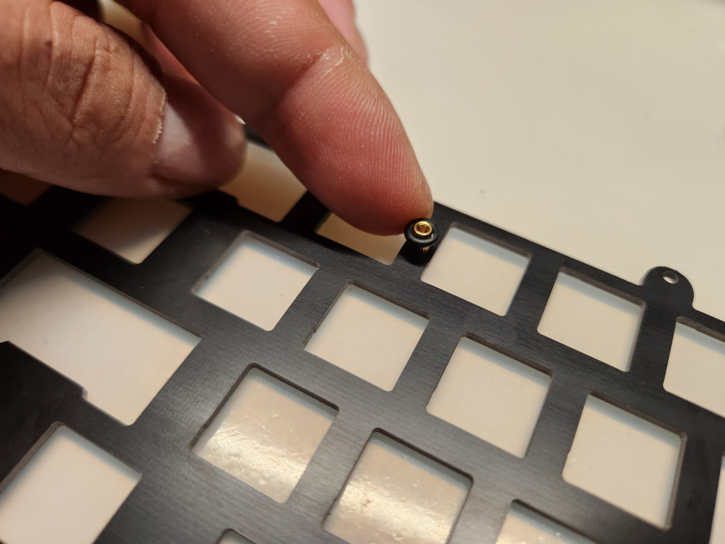
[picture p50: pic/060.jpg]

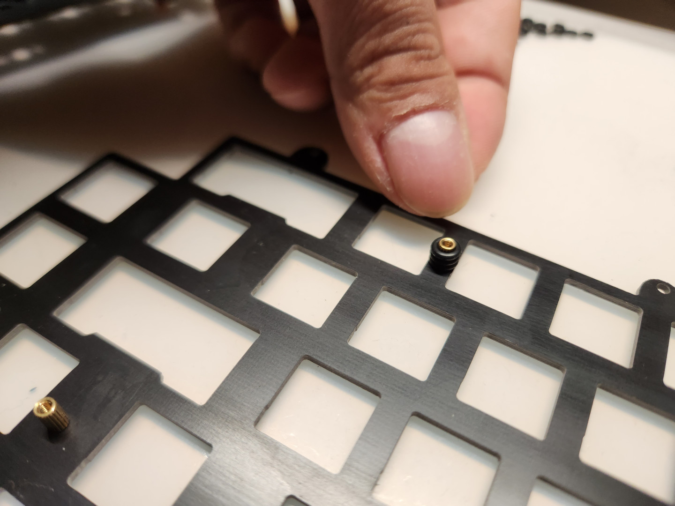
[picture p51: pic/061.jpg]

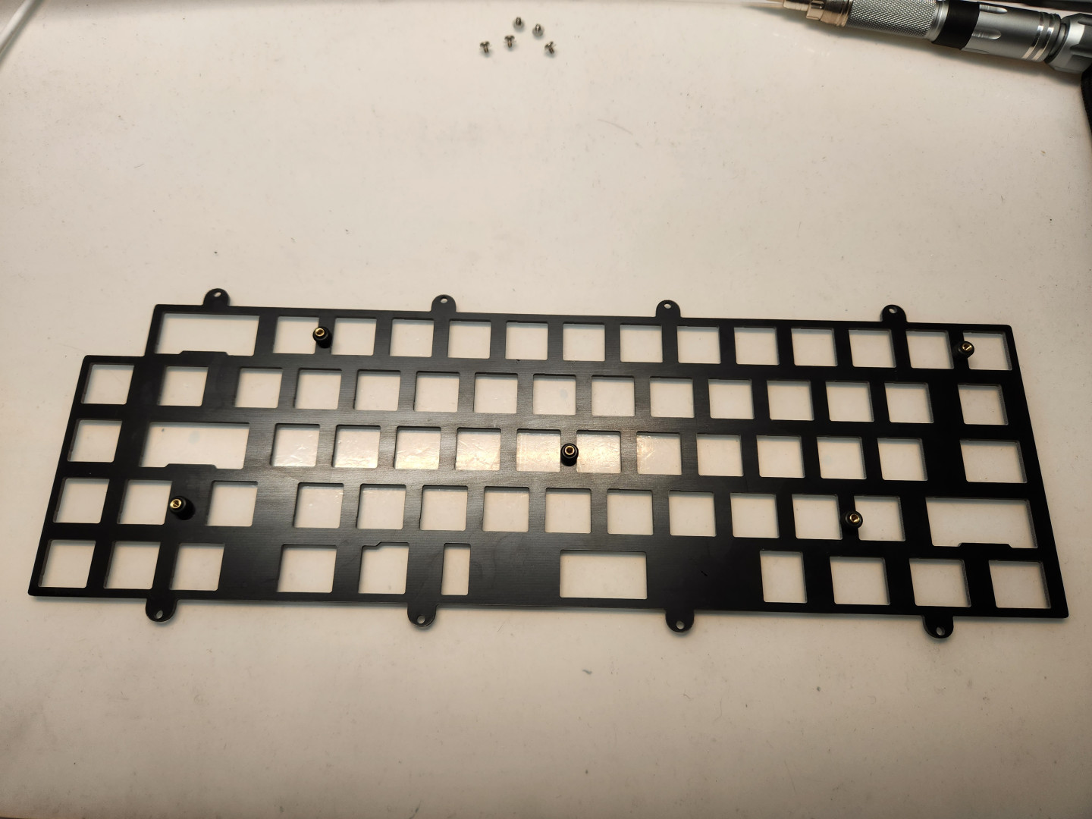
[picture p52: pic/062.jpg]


- 接著再將PCB及定位板合併在一起。
- Next, combine the PCB and the positioning board together.

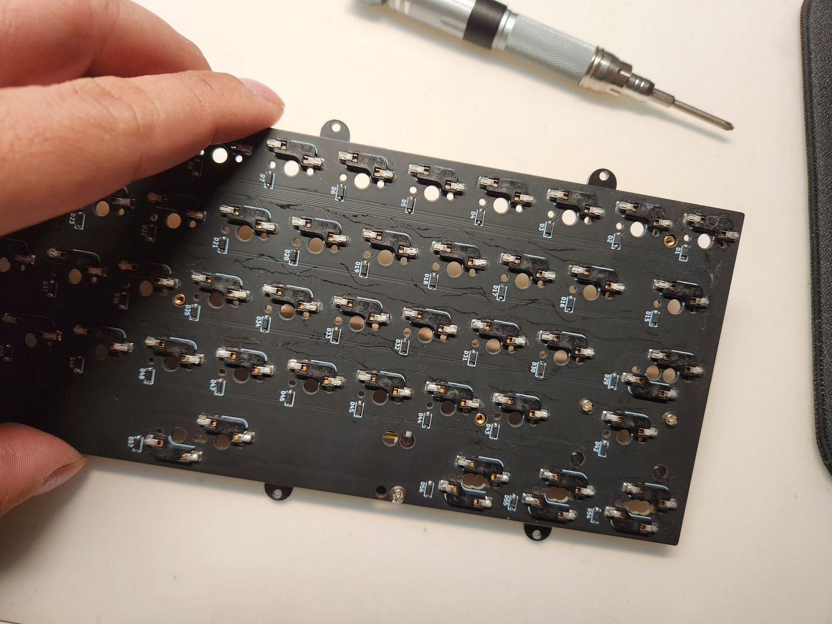
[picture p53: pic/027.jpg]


- 從背面加上墊片後，再繼續鎖上螺絲固定。
- After adding the washers from the back side, then continue to lock the screws to secure it.

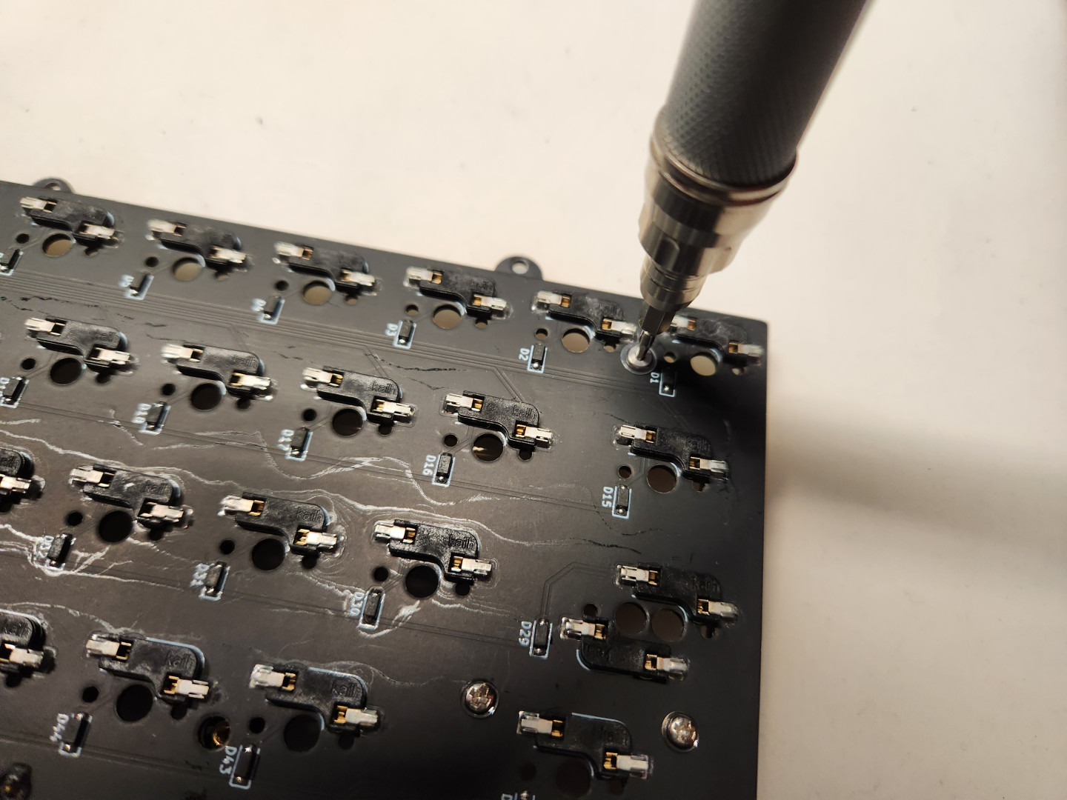
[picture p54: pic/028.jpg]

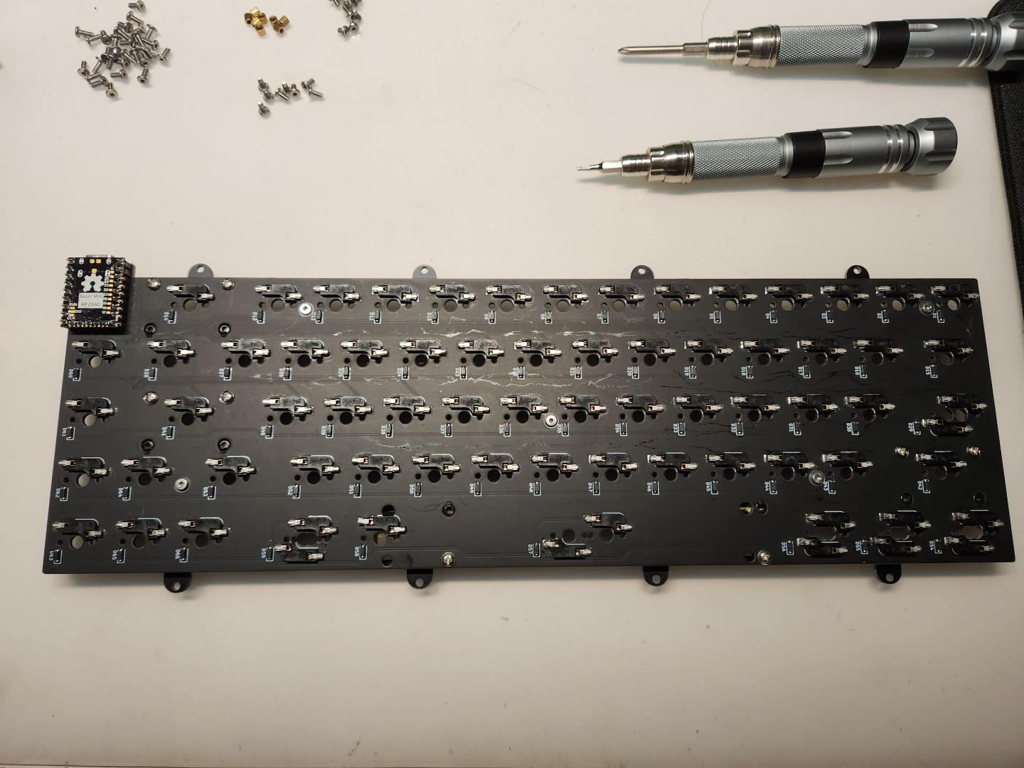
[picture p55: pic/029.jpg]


- 這裡我會推薦先將鍵軸固定在定位板及PCB上，會比較好安裝。
- Here I would recommend to fix the switches on the plate and PCB first, it will be better for installation.

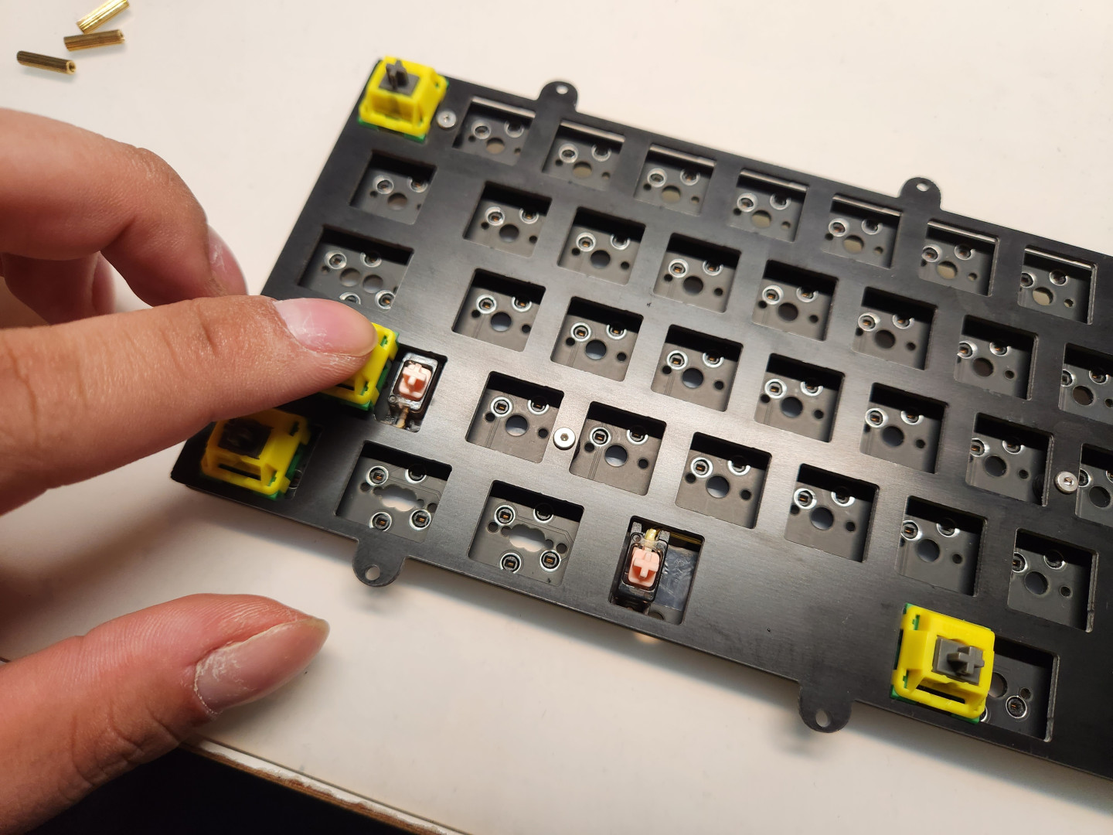
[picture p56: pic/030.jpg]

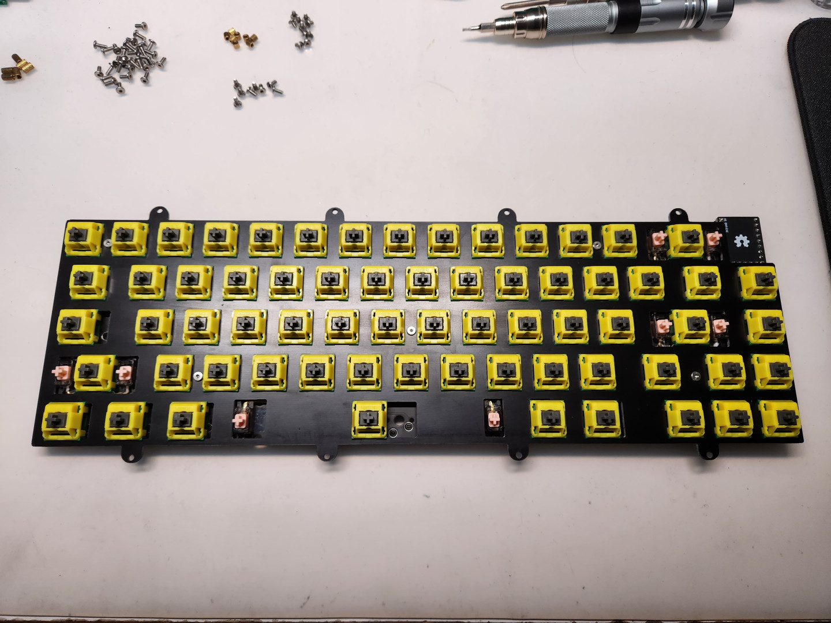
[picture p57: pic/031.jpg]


## 四、外殼組裝（Install Case）

- 這裡的照片是舊的，不過不會影響安裝；首先將所有定製的壓克力外框上頭的保護紙撕除。
- Here's an old photo, but it won't affect the installation; first remove the protective paper from the top of all arcylic cases.

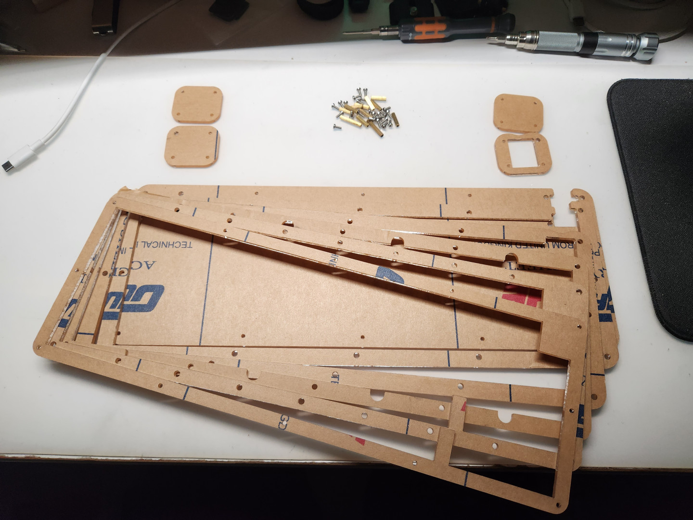
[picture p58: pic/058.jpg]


- 首先我們從第一層開始安裝，這邊準備好`M2x4mm`、`M2x5mm`螺絲；`M2x3mm`、`M2x12mm`、`M2x18mm`銅柱。
- First we start on the first plate, prepare `M2x4mm`, `M2x4mm` screws; `M2x3mm`, `M2x12mm`, `M2x18mm` spacers. 



- M2x18mm銅柱、M2x5mm螺絲。
- M2x18mm spacers, M2x5mm screws.



- M2x12mm銅柱、M2x5mm螺絲。
- M2x12mm spacers, M2x5mm screws.



- M2x3mm銅柱、M2x4mm螺絲。
- M2x3mm spacers, M2x4mm screws.



- 接著依序將第二層、三層堆疊上去。
- Next put the second, third plate stacking together.




- 再來將PCB及定位板用`M2x3mm`螺絲固定上去。
- Then fix the PCB and plate with `M2x3mm` screws.




- PCB固定好之後，再將第四、五層疊上去。
- After fixing the PCB and plate, then put stacking the 4th plate.



- 接著將第六層底板拿出來，使用`M2x5mm`螺絲，在照片上的位置安裝`M2x5mm`銅柱
- Next you need to use `M2x5mm` screws, install `M2x5mm` spacers like the picture below.



- 再來將第六層堆疊上去，用`M2x5mm`螺絲將外殼固定好。
- Then stacking the 6th plate, and use `M2x5mm` screws to lock the case.





- 接著將第七、八層、M2x5mm螺絲、M2x5mm銅柱拿出來，依照照片上的位置安裝。
- Then you need to install `M2x5mm` screws and spacers on the 7th/8th plate, like picture.



- 最後將左右邊的腳放在鍵盤上，用M2x5mm、M2x3mm螺絲固定好。
- Last step, putting the 7th/8th plate on left and right side, then use `M2x5mm`, `M2x3mm` screws screw the case.








- 將腳墊安裝上去。
- Install the rubber feets.



- 這樣就完成了。
- Done。





> **Note**
>
> 最後就是將鍵盤接到電腦上測試按鍵，確定沒有問題後就可以開始使用了。
>
> The last thing you need to do is to connect the keyboard to your computer and test the keys to make sure there is no problem and then you can start using it.

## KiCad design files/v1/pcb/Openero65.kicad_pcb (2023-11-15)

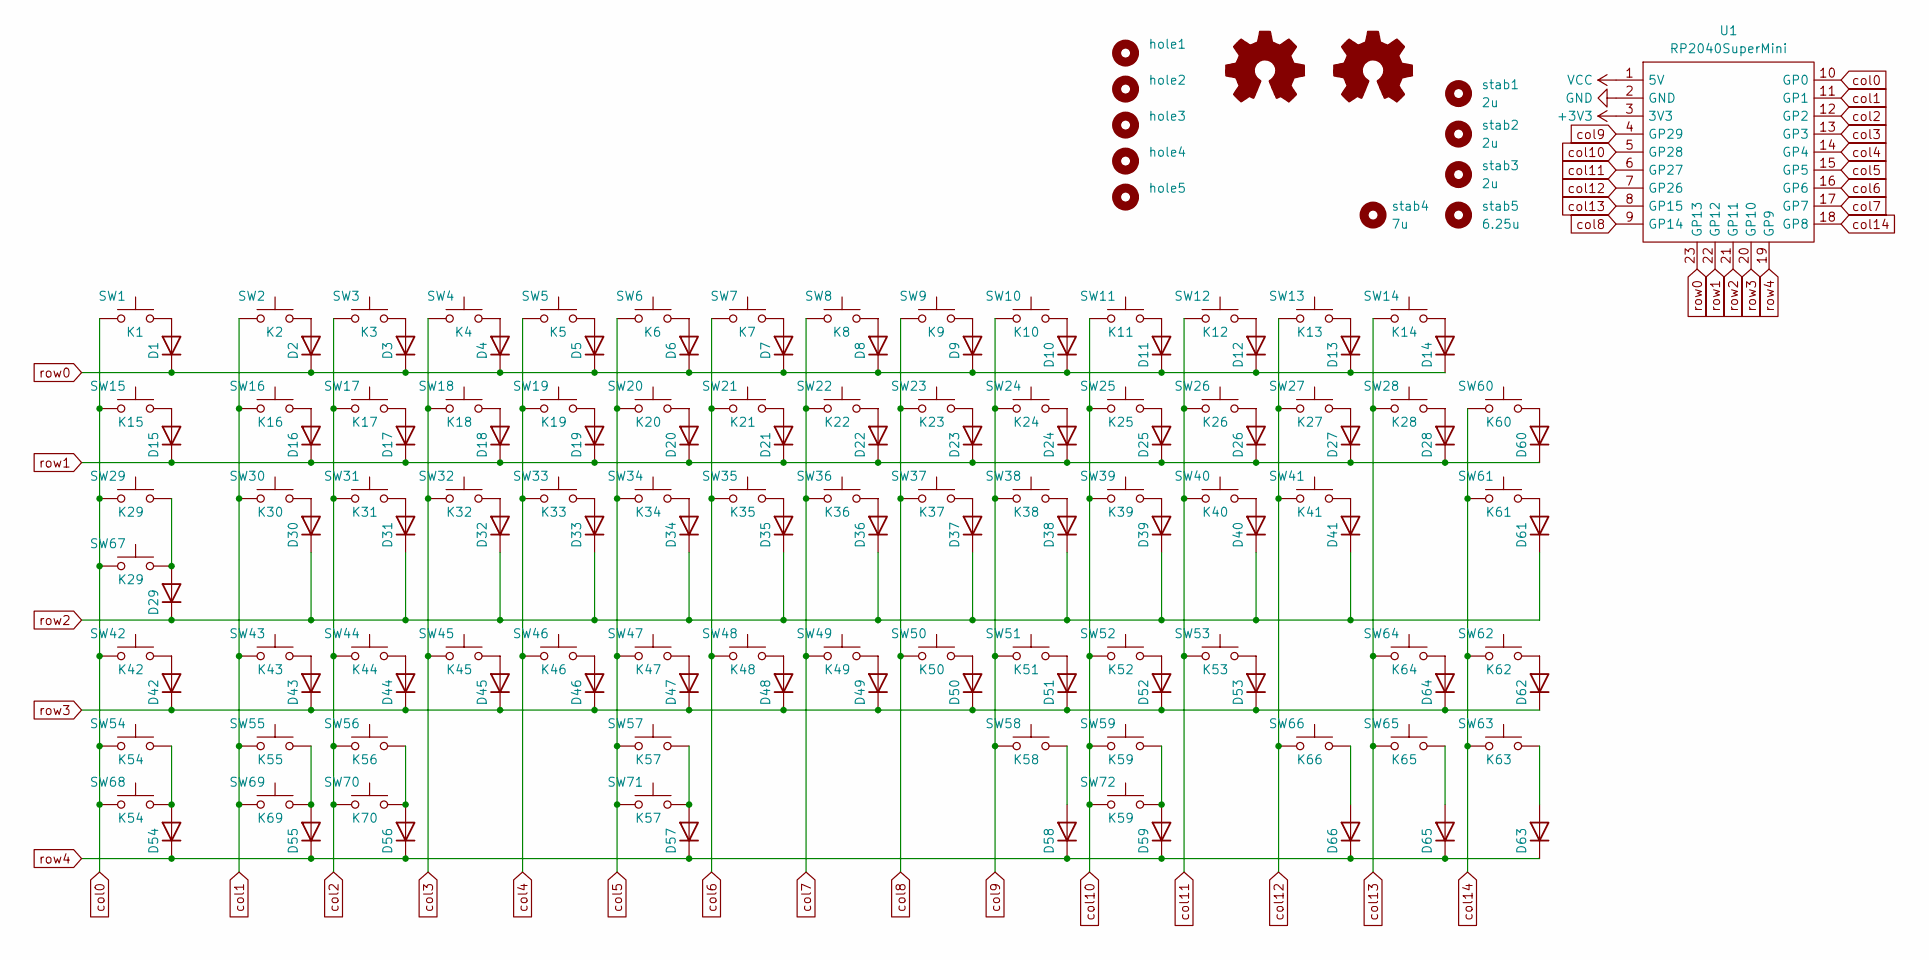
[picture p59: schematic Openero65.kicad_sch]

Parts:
D1, D2, D3, D4, D5, D6, D7, D8, D9, D10, D11, D12, D13, D14, D15, D16, D17, D18, D19, D20, D21, D22, D23, D24, D25, D26, D27, D28, D29, D30, D31, D32, D33, D34, D35, D36, D37, D38, D39, D40, D41, D42, D43, D44, D45, D46, D47, D48, D49, D50, D51, D52, D53, D54, D55, D56, D57, D58, D59, D60, D61, D62, D63, D64, D65, D66: 1N4148; D_SOD-123
SW1: K1; SW_Hotswap_Kailh_MX_Plated_1.00u
SW2: K2; SW_Hotswap_Kailh_MX_Plated_1.00u
SW3: K3; SW_Hotswap_Kailh_MX_Plated_1.00u
SW4: K4; SW_Hotswap_Kailh_MX_Plated_1.00u
SW5: K5; SW_Hotswap_Kailh_MX_Plated_1.00u
SW6: K6; SW_Hotswap_Kailh_MX_Plated_1.00u
SW7: K7; SW_Hotswap_Kailh_MX_Plated_1.00u
SW8: K8; SW_Hotswap_Kailh_MX_Plated_1.00u
SW9: K9; SW_Hotswap_Kailh_MX_Plated_1.00u
SW10: K10; SW_Hotswap_Kailh_MX_Plated_1.00u
SW11: K11; SW_Hotswap_Kailh_MX_Plated_1.00u
SW12: K12; SW_Hotswap_Kailh_MX_Plated_1.00u
SW13: K13; SW_Hotswap_Kailh_MX_Plated_1.00u
SW14: K14; SW_Hotswap_Kailh_MX_Plated_2.00u
SW15: K15; SW_Hotswap_Kailh_MX_Plated_1.50u
SW16: K16; SW_Hotswap_Kailh_MX_Plated_1.00u
SW17: K17; SW_Hotswap_Kailh_MX_Plated_1.00u
SW18: K18; SW_Hotswap_Kailh_MX_Plated_1.00u
SW19: K19; SW_Hotswap_Kailh_MX_Plated_1.00u
SW20: K20; SW_Hotswap_Kailh_MX_Plated_1.00u
SW21: K21; SW_Hotswap_Kailh_MX_Plated_1.00u
SW22: K22; SW_Hotswap_Kailh_MX_Plated_1.00u
SW23: K23; SW_Hotswap_Kailh_MX_Plated_1.00u
SW24: K24; SW_Hotswap_Kailh_MX_Plated_1.00u
SW25: K25; SW_Hotswap_Kailh_MX_Plated_1.00u
SW26: K26; SW_Hotswap_Kailh_MX_Plated_1.00u
SW27: K27; SW_Hotswap_Kailh_MX_Plated_1.00u
SW28: K28; SW_Hotswap_Kailh_MX_Plated_1.50u
SW29: K29; SW_Hotswap_Kailh_MX_Plated_1.75u
SW30: K30; SW_Hotswap_Kailh_MX_Plated_1.00u
SW31: K31; SW_Hotswap_Kailh_MX_Plated_1.00u
SW32: K32; SW_Hotswap_Kailh_MX_Plated_1.00u
SW33: K33; SW_Hotswap_Kailh_MX_Plated_1.00u
SW34: K34; SW_Hotswap_Kailh_MX_Plated_1.00u
SW35: K35; SW_Hotswap_Kailh_MX_Plated_1.00u
SW36: K36; SW_Hotswap_Kailh_MX_Plated_1.00u
SW37: K37; SW_Hotswap_Kailh_MX_Plated_1.00u
SW38: K38; SW_Hotswap_Kailh_MX_Plated_1.00u
SW39: K39; SW_Hotswap_Kailh_MX_Plated_1.00u
SW40: K40; SW_Hotswap_Kailh_MX_Plated_1.00u
SW41: K41; SW_Hotswap_Kailh_MX_Plated_2.25u
SW42: K42; SW_Hotswap_Kailh_MX_Plated_2.25u
SW43: K43; SW_Hotswap_Kailh_MX_Plated_1.00u
SW44: K44; SW_Hotswap_Kailh_MX_Plated_1.00u
SW45: K45; SW_Hotswap_Kailh_MX_Plated_1.00u
SW46: K46; SW_Hotswap_Kailh_MX_Plated_1.00u
SW47: K47; SW_Hotswap_Kailh_MX_Plated_1.00u
SW48: K48; SW_Hotswap_Kailh_MX_Plated_1.00u
SW49: K49; SW_Hotswap_Kailh_MX_Plated_1.00u
SW50: K50; SW_Hotswap_Kailh_MX_Plated_1.00u
SW51: K51; SW_Hotswap_Kailh_MX_Plated_1.00u
SW52: K52; SW_Hotswap_Kailh_MX_Plated_1.00u
SW53: K53; SW_Hotswap_Kailh_MX_Plated_1.75u
SW54: K54; SW_Hotswap_Kailh_MX_Plated_1.25u
SW55: K55; SW_Hotswap_Kailh_MX_Plated_1.25u
SW56: K56; SW_Hotswap_Kailh_MX_Plated_1.25u
SW57: K57; SW_Hotswap_Kailh_MX_Plated_6.25u
SW58: K58; SW_Hotswap_Kailh_MX_Plated_1.25u
SW59: K59; SW_Hotswap_Kailh_MX_Plated_1.25u
SW60: K60; SW_Hotswap_Kailh_MX_Plated_1.00u
SW61: K61; SW_Hotswap_Kailh_MX_Plated_1.00u
SW62: K62; SW_Hotswap_Kailh_MX_Plated_1.00u
SW63: K63; SW_Hotswap_Kailh_MX_Plated_1.00u
SW64: K64; SW_Hotswap_Kailh_MX_Plated_1.00u
SW65: K65; SW_Hotswap_Kailh_MX_Plated_1.00u
SW66: K66; SW_Hotswap_Kailh_MX_Plated_1.00u
SW67: K29; SW_Hotswap_Kailh_MX_Plated_1.25u
SW68: K54; SW_Hotswap_Kailh_MX_Plated_1.50u
SW69: K69; SW_Hotswap_Kailh_MX_Plated_1.00u
SW70: K70; SW_Hotswap_Kailh_MX_Plated_1.50u
SW71: K57; SW_Hotswap_Kailh_MX_Plated_7.00u
SW72: K59; SW_Hotswap_Kailh_MX_Plated_1.50u
U1: RP2040SuperMini; MCU_RP2040SuperMini
hole1, hole2, hole3, hole4, hole5: MountingHole_3.5mm
stab1, stab2, stab3: 2u; Stabilizer_Cherry_MX_2.00u
stab4: 7u; Stabilizer_Cherry_MX_7.00u
stab5: 6.25u; Stabilizer_Cherry_MX_6.25u

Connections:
+3V3: U1.3 (3V3)
GND: U1.2 (GND)
unnamed: D1.2 (A), SW1.2
unnamed: D2.2 (A), SW2.2
unnamed: D3.2 (A), SW3.2
unnamed: D4.2 (A), SW4.2
unnamed: D5.2 (A), SW5.2
unnamed: D6.2 (A), SW6.2
unnamed: D7.2 (A), SW7.2
unnamed: D8.2 (A), SW8.2
unnamed: D9.2 (A), SW9.2
unnamed: D10.2 (A), SW10.2
unnamed: D11.2 (A), SW11.2
unnamed: D12.2 (A), SW12.2
unnamed: D13.2 (A), SW13.2
unnamed: D14.2 (A), SW14.2
unnamed: D15.2 (A), SW15.2
unnamed: D16.2 (A), SW16.2
unnamed: D17.2 (A), SW17.2
unnamed: D18.2 (A), SW18.2
unnamed: D19.2 (A), SW19.2
unnamed: D20.2 (A), SW20.2
unnamed: D21.2 (A), SW21.2
unnamed: D22.2 (A), SW22.2
unnamed: D23.2 (A), SW23.2
unnamed: D24.2 (A), SW24.2
unnamed: D25.2 (A), SW25.2
unnamed: D26.2 (A), SW26.2
unnamed: D27.2 (A), SW27.2
unnamed: D28.2 (A), SW28.2
unnamed: D29.2 (A), SW29.2, SW67.2
unnamed: D30.2 (A), SW30.2
unnamed: D31.2 (A), SW31.2
unnamed: D32.2 (A), SW32.2
unnamed: D33.2 (A), SW33.2
unnamed: D34.2 (A), SW34.2
unnamed: D35.2 (A), SW35.2
unnamed: D36.2 (A), SW36.2
unnamed: D37.2 (A), SW37.2
unnamed: D38.2 (A), SW38.2
unnamed: D39.2 (A), SW39.2
unnamed: D40.2 (A), SW40.2
unnamed: D41.2 (A), SW41.2
unnamed: D42.2 (A), SW42.2
unnamed: D43.2 (A), SW43.2
unnamed: D44.2 (A), SW44.2
unnamed: D45.2 (A), SW45.2
unnamed: D46.2 (A), SW46.2
unnamed: D47.2 (A), SW47.2
unnamed: D48.2 (A), SW48.2
unnamed: D49.2 (A), SW49.2
unnamed: D50.2 (A), SW50.2
unnamed: D51.2 (A), SW51.2
unnamed: D52.2 (A), SW52.2
unnamed: D53.2 (A), SW53.2
unnamed: D54.2 (A), SW54.2, SW68.2
unnamed: D55.2 (A), SW55.2, SW69.2
unnamed: D56.2 (A), SW56.2, SW70.2
unnamed: D57.2 (A), SW57.2, SW71.2
unnamed: D58.2 (A), SW58.2
unnamed: D59.2 (A), SW59.2, SW72.2
unnamed: D60.2 (A), SW60.2
unnamed: D61.2 (A), SW61.2
unnamed: D62.2 (A), SW62.2
unnamed: D63.2 (A), SW63.2
unnamed: D64.2 (A), SW64.2
unnamed: D65.2 (A), SW65.2
unnamed: D66.2 (A), SW66.2
VCC: U1.1 (5V)
col0: SW1.1, SW15.1, SW29.1, SW42.1, SW54.1, SW67.1, SW68.1, U1.10 (GP0)
col1: SW2.1, SW16.1, SW30.1, SW43.1, SW55.1, SW69.1, U1.11 (GP1)
col2: SW3.1, SW17.1, SW31.1, SW44.1, SW56.1, SW70.1, U1.12 (GP2)
col3: SW4.1, SW18.1, SW32.1, SW45.1, U1.13 (GP3)
col4: SW5.1, SW19.1, SW33.1, SW46.1, U1.14 (GP4)
col5: SW6.1, SW20.1, SW34.1, SW47.1, SW57.1, SW71.1, U1.15 (GP5)
col6: SW7.1, SW21.1, SW35.1, SW48.1, U1.16 (GP6)
col7: SW8.1, SW22.1, SW36.1, SW49.1, U1.17 (GP7)
col8: SW9.1, SW23.1, SW37.1, SW50.1, U1.9 (GP14)
col9: SW10.1, SW24.1, SW38.1, SW51.1, SW58.1, U1.4 (GP29)
col10: SW11.1, SW25.1, SW39.1, SW52.1, SW59.1, SW72.1, U1.5 (GP28)
col11: SW12.1, SW26.1, SW40.1, SW53.1, U1.6 (GP27)
col12: SW13.1, SW27.1, SW41.1, SW66.1, U1.7 (GP26)
col13: SW14.1, SW28.1, SW64.1, SW65.1, U1.8 (GP15)
col14: SW60.1, SW61.1, SW62.1, SW63.1, U1.18 (GP8)
row0: D1.1 (K), D2.1 (K), D3.1 (K), D4.1 (K), D5.1 (K), D6.1 (K), D7.1 (K), D8.1 (K), D9.1 (K), D10.1 (K), D11.1 (K), D12.1 (K), D13.1 (K), D14.1 (K), U1.23 (GP13)
row1: D15.1 (K), D16.1 (K), D17.1 (K), D18.1 (K), D19.1 (K), D20.1 (K), D21.1 (K), D22.1 (K), D23.1 (K), D24.1 (K), D25.1 (K), D26.1 (K), D27.1 (K), D28.1 (K), D60.1 (K), U1.22 (GP12)
row2: D29.1 (K), D30.1 (K), D31.1 (K), D32.1 (K), D33.1 (K), D34.1 (K), D35.1 (K), D36.1 (K), D37.1 (K), D38.1 (K), D39.1 (K), D40.1 (K), D41.1 (K), D61.1 (K), U1.21 (GP11)
row3: D42.1 (K), D43.1 (K), D44.1 (K), D45.1 (K), D46.1 (K), D47.1 (K), D48.1 (K), D49.1 (K), D50.1 (K), D51.1 (K), D52.1 (K), D53.1 (K), D62.1 (K), D64.1 (K), U1.20 (GP10)
row4: D54.1 (K), D55.1 (K), D56.1 (K), D57.1 (K), D58.1 (K), D59.1 (K), D63.1 (K), D65.1 (K), D66.1 (K), U1.19 (GP9)

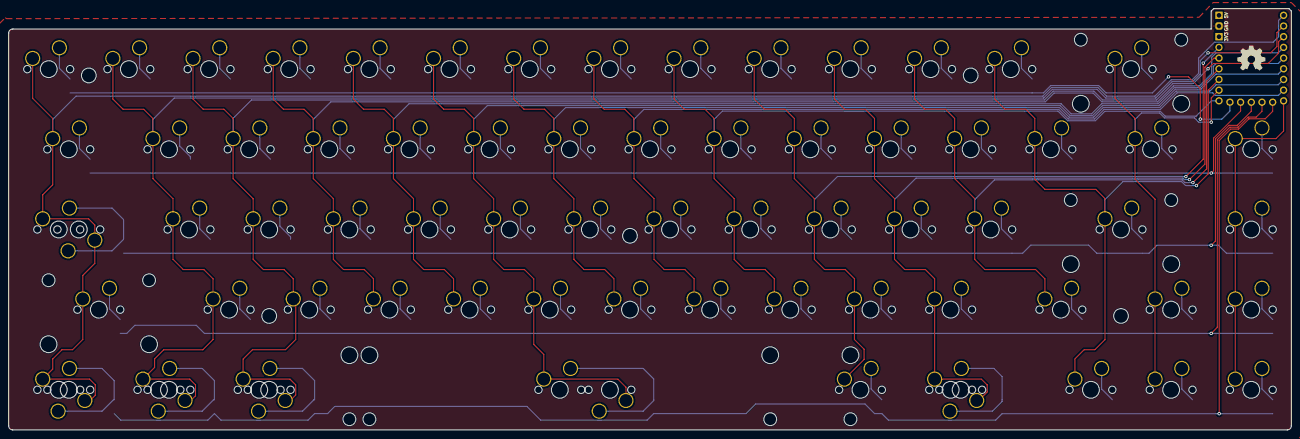
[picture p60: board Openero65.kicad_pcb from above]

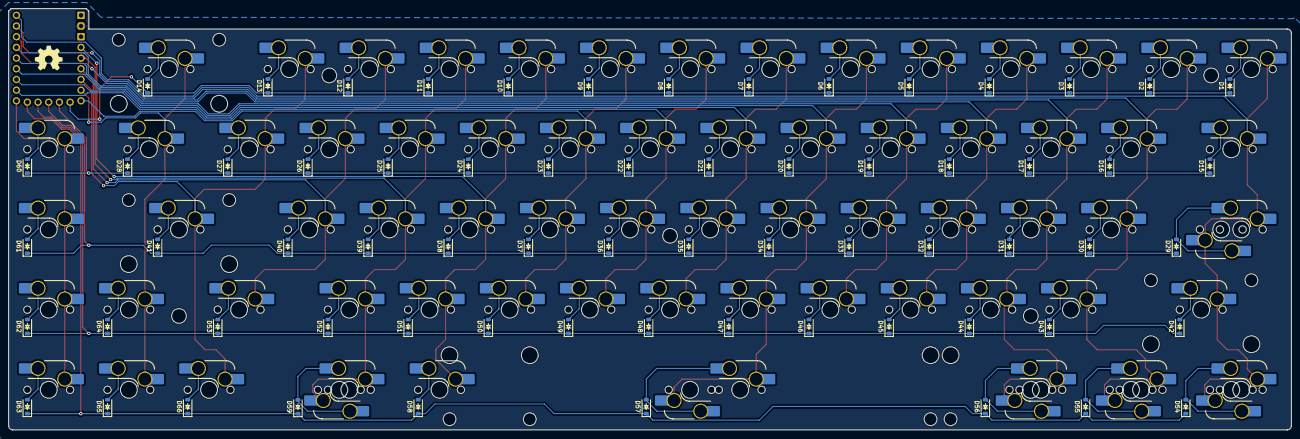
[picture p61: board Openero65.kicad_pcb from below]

Board: 2 copper layers, 304.8 x 100.1 mm, 149 parts (66 on the bottom side), 86 nets.

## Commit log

2023-11-15 update v1
    [1.step, 2.step, 3.step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]
2023-11-16 fix case 2
    [2.step]
2023-11-17 fix case 1&2
    [1.step, 2.step]
2023-11-18 fix plate
    [2.step, 3.step, plate.step]
2023-11-18 move plate.step
    [plate.step]
2023-11-19 fix usb-c cable outer hole
    [1.step, 2.step, 3.step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]
2023-11-19 fix files on the z
    [1.step, 2.step, 3.step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]
2023-11-23 add wkl case
    [1.step, 2.step]
2023-11-30 fix case
    [2.step, 5.step, 6.step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]
2023-11-30 fix case and usb port
    [1.step, 2.step, 3.step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]
2023-12-05 fix wk case
    [1.step, 2.step]
2023-12-11 fix wkl case
    [1.step, 2.step]
2023-12-20 fix case 3
    [3.step]
